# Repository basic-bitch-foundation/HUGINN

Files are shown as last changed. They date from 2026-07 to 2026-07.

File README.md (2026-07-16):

# HUGINN
 Introduction
--------------------------------------------
Huginn was crow of Odin (Greek God), He was messenger of hims. Thus this will be your personal messenger, let u communicate w/ hommies in any 9 realms.

It is a LoRa ( Long Range ) powered  pocket off grid pager.

## Build

It have BOM, Custom PCB, 3D printed Enclosure, buttons and suport.
Download All files(.stp) from Enclosure printable folder and print 'em
 > It uses M2 screw everywhere
 > For part link please download .odf not .csv
 > In assembly u may see the MCU as colliding with PCB dw! it just cz I can't remove the header pins. :lollll:

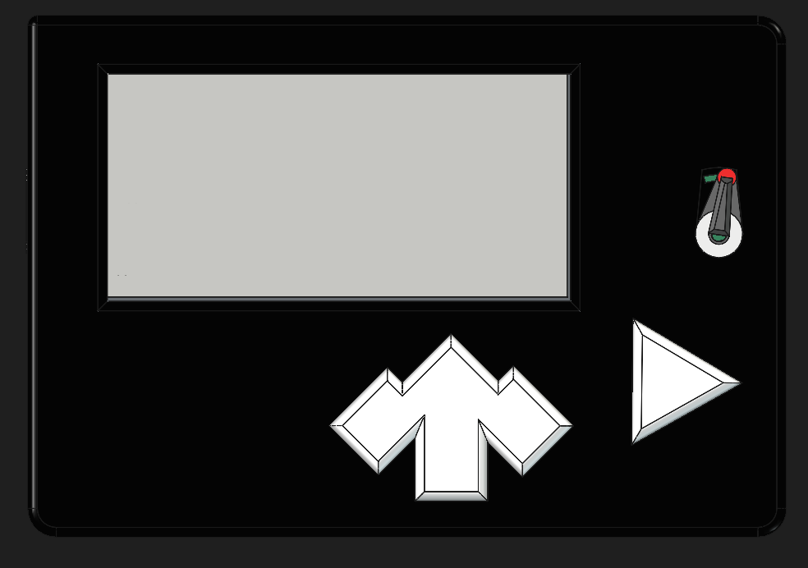
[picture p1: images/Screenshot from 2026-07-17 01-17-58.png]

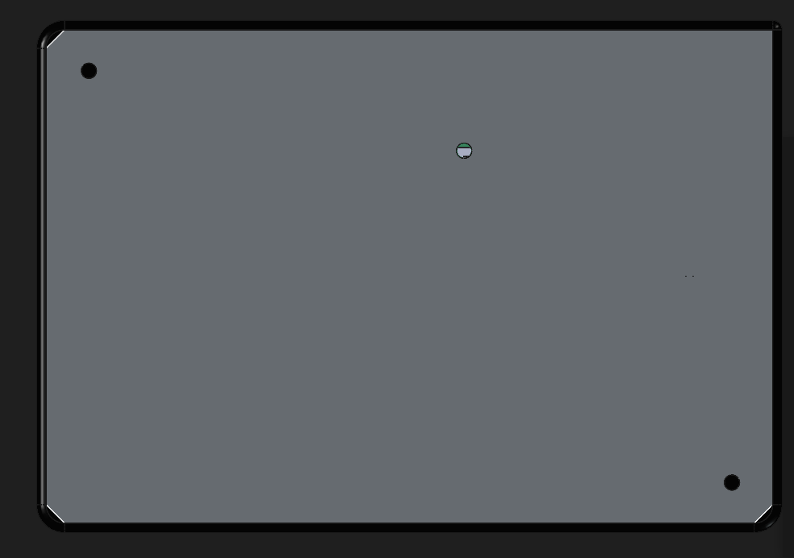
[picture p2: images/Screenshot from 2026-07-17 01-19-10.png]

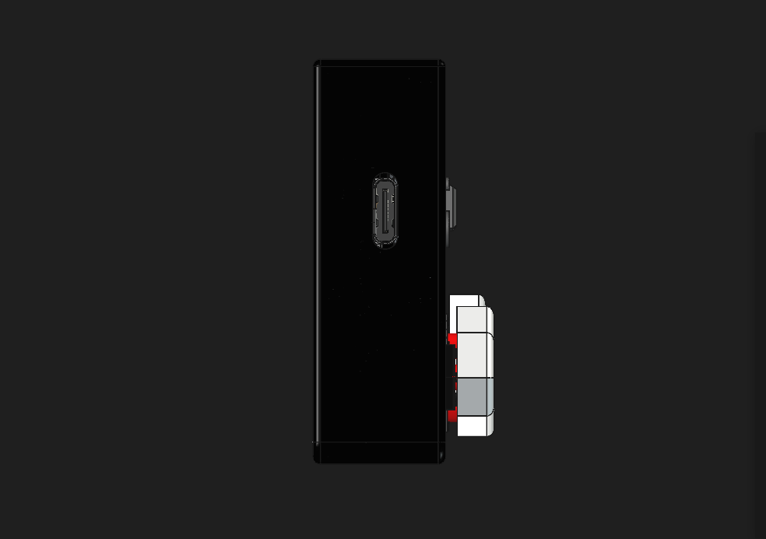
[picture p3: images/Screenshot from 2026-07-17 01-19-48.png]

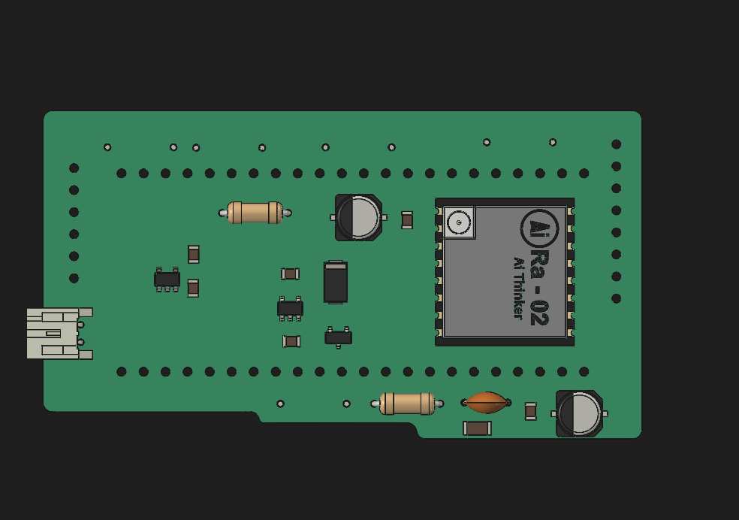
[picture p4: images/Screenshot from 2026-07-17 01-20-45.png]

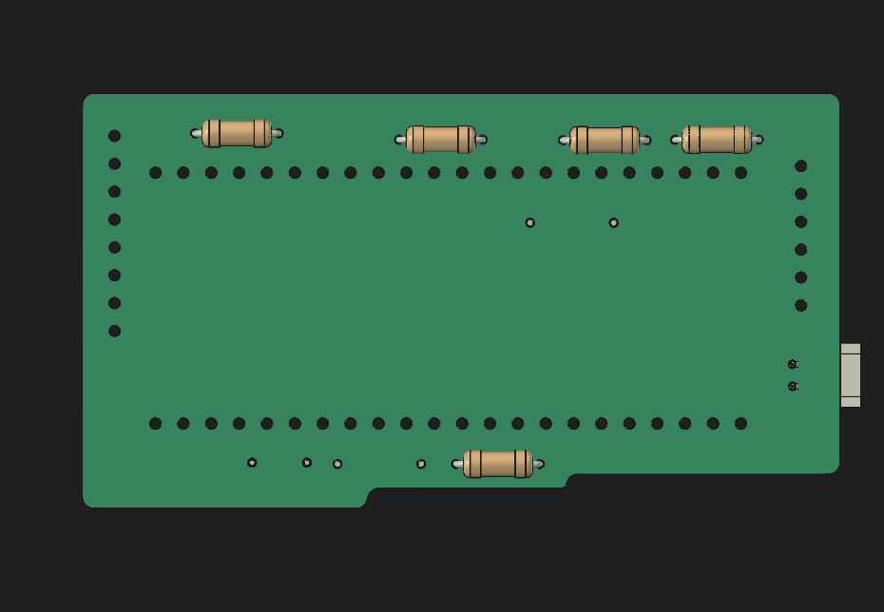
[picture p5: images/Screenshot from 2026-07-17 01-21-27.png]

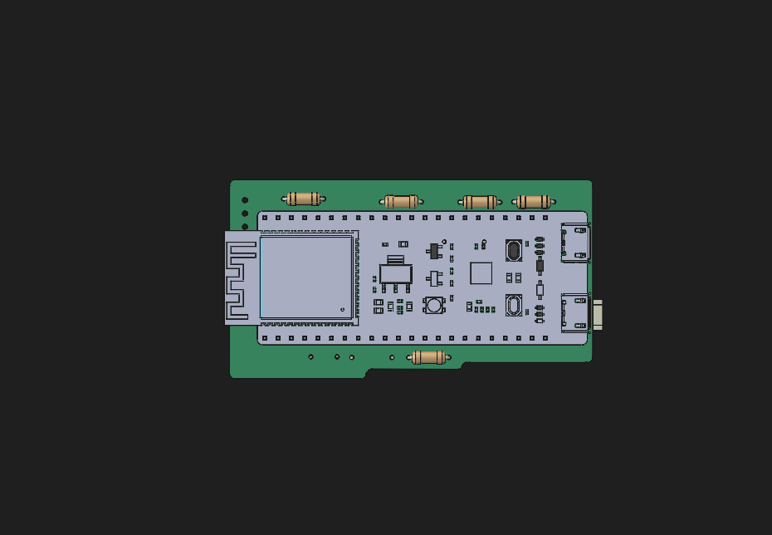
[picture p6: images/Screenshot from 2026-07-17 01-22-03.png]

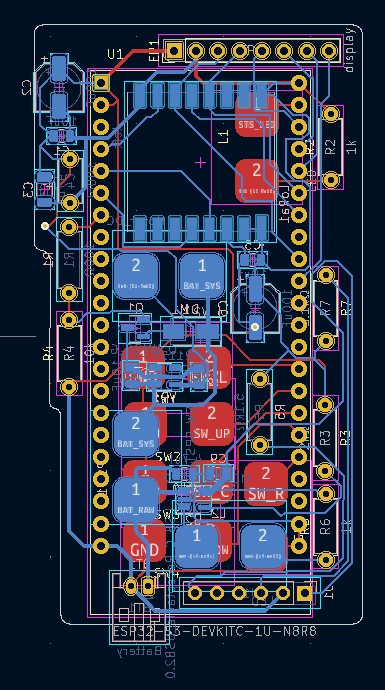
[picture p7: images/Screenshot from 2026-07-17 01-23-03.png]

 ### Instructions
 First comes the MCU U hve to castellated solder it on top of the board or can use very low height header pins

 then Display as display I gave in BOM, Have 8 pin(Goes to HAT) to 8 , I will suggest to solder 'em direct , though half height n 2.54 header can use.
 
 Stating with solder all component On PCB ,
 As most part will be connected using wire to component to SMD solder Pad.
 1. Part u need to connect like this: ( Component--> wire--> Smd pad)
 > 5 switches
 >2 LEDs
 >Battery (optional)

 2. The semi rotating switch have two part one is switch with rod dropped and a pad
 put the switch inside carv and then fix the pad on left face of rod so i can press momentary switch.
 Then, Screw it from bellow (Enough clamp so that It can't move freely but can move!)

 3. As most part have support in Enclosure but gluing it make it smooth
 4. Glue the disc motor that will send vibration through body
 5. I don't gave the outing for LED cz It was ruining the Aesthetics of E ink's calm there so Any who want to see the charging status can place it nea usb input or a small hole behind panel

## Code
This is basic firmware code u can compile and flash it in MCU using Platform.io (a extension in VS code) or using Thonny (IDE)

## How to use it:
As pager need to be quick I added three code fn!
and a local converter:
So U navigate up/down 
between
143 ( I Love u!)
505 ( SOS )
etc.
the click the send button when reciver will reciver get it wil automaticall converted in their own device
. This save the bytes of daya is trasmitting and saving time 

# AI- decl.
I use like very little < 10% AI for code. 

# Outro
Made for Hackclub <3 by Saksham (A.K.A bbb)
Feel free to contribute :heart:

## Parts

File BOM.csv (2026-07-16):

Reference | Qty | Category | Component | Value | Manufacturer | Part Number / Model | Package / Footprint | Description | Supplier Link | Price (USD) | Price (INR) | Notes
U1 | 1 | Microcontrollers | ESP32-S3 Dev Board | N8R8 | Espressif | ESP32-S3-DEVKITC-1-N8R8 | DEVKITC-1U (castellated module) | ESP32-S3 Development Board (8MB Flash / 8MB PSRAM) | here |  | 1304.1 | Used as system module - not a bare SoC
LoRa1 | 1 | RF Modules | LoRa Transceiver Module | 433MHz | Ai-Thinker | RA-02 (SX1278) | SMD Module - 16 pin (2x8 top/bottom) | 433 MHz LoRa Transceiver Module (SX1278-based) | here |  | 301 | Confirm 433 MHz vs 868/915 MHz variant needed for your region
VR1 | 1 | Power Management | LDO Voltage Regulator | 3.3V | Diodes Inc. | AP2112K-3.3 | SOT-23-5 | 3.3V 600mA Low Dropout Voltage Regulator | here |  | 26
U2 | 1 | Power Management | LiPo Charge Controller IC | - | Microchip | MCP73831T-2ACI/OT | SOT-23-5 | Single-Cell Li-Po/Li-Ion Linear Charge Management IC | here |  | 71.83
J1 | 1 | Connectors | USB Type-C Receptacle | - |  |  | SMD Type-C 16-pin | USB Type-C Power/Data Connector (USB 2.0) | here |  | 34 | different from footprint
BT1 | 1 | Connectors | Battery Connector | 2-pin | JST | PH-2 (S2B-PH-K) | JST-PH 2.00mm 2-pin Horizontal | JST-PH 2-Pin Battery Connector | here |  | 8 | Can skip very optional
EP1 | 1 | Connectors | E-Ink Display Connector | 8-pin | Generic | PinHeader-1x08-2.54mm | 2.54mm Pitch 1x08 Vertical Header | 2.13" SPI E-Ink Display Header (8-pin) | here |  | 1478
PSW1 | 1 | Switches | Momentary switch | Power | Generic |  | SMD 2-pin |  | here |  | 39
SW1 | 1 | Switches | Tactile Push Button | Left | Generic | Tactile SMD 2-pin | SolderPad 5x5mm SMD | Tactile Push Button (Left / Navigation) | here |  | 1.05
SW2 | 1 | Switches | Tactile Push Button | Up | Generic | Tactile SMD 2-pin | SolderPad 5x5mm SMD | Tactile Push Button (Up / Navigation) | "
SW3 | 1 | Switches | Tactile Push Button | Send | Generic | Tactile SMD 2-pin | SolderPad 5x5mm SMD | Tactile Push Button (Center / Select) | "
SW4 | 1 | Switches | Tactile Push Button | Down | Generic | Tactile SMD 2-pin | SolderPad 5x5mm SMD | Tactile Push Button (Down / Navigation) | "
SW5 | 1 | Switches | Tactile Push Button | Right | Generic | Tactile SMD 2-pin | SolderPad 5x5mm SMD | Momentary Tactile Push Button (Right / Navigation) | here
L1 | 1 | LEDs | Status LED | diode led | Generic | LED-0805 | SolderPad 5x5mm SMD | Status Indicator LED
L2 | 1 | LEDs | Charge Status LED | " | Generic | LED-0805 | SolderPad 5x5mm SMD | Battery Charge Status LED
Q1 | 1 | Transistors | N-Channel MOSFET | - | Generic | BSS138 | SOT-23 | N-Channel MOSFET (Motor Driver Switch) | here |  | 2.02
D1 | 1 | Diodes | Flyback/Protection Diode | - | Generic | 1N4148 or equiv. | SMA | Diode (Motor Flyback Protection)
R1 | 1 | Resistors | Resistor | 100? | Generic | RC-Series | Axial THT (DIN0207) | 100? Resistor (LoRa Reset Gate)
R2 | 1 | Resistors | Resistor | 1k? | Generic | RC-Series | Axial THT (DIN0207) | 1k? Resistor (Status LED Current Limit) |  |  |  | regional prices and availiblity varries
R3 | 1 | Resistors | Resistor | 2k? | Generic | RC-Series | Axial THT (DIN0207) | 2k? Resistor (Charge IC PROG - Sets Charge Current) |  |  |  | regional prices and availiblity varries
R4 | 1 | Resistors | Resistor | 10k? | Generic | RC-Series | Axial THT (DIN0207) | 10k? Resistor (MOSFET Gate Pulldown) |  |  |  | regional prices and availiblity varries
R5 | 1 | Resistors | Resistor | 5.1k? | Generic | RC-Series | Axial THT (DIN0207) | 5.1k? Resistor (USB-C CC1 Pull-down) |  |  |  | regional prices and availiblity varries
R6 | 1 | Resistors | Resistor | 1k? | Generic | RC-Series | Axial THT (DIN0207) | 1k? Resistor (Charge LED Current Limit)
R7 | 1 | Resistors | Resistor | 5.1k? | Generic | RC-Series | Axial THT (DIN0207) | 5.1k? Resistor (USB-C CC2 Pull-down)
C1 | 1 | Capacitors | Capacitor | 10uF | Generic | C-Series | 0805 SMD | 10uF Ceramic Capacitor (E-Ink Supply Decoupling)
C2 | 1 | Capacitors | Capacitor | 100uF | Generic | CP-Elec | 5x5.3mm Electrolytic | 100uF Electrolytic Capacitor (E-Ink Bulk Decoupling)
C3 | 1 | Capacitors | Capacitor | 47uF | Generic | C-Series | 1206 SMD | 47uF Capacitor (ESP32 Supply Decoupling)
C4 | 1 | Capacitors | Capacitor | 100nF | Generic | C-Disc | THT Disc 5mm | 100nF Capacitor (ESP32 Supply Decoupling)
C5 | 1 | Capacitors | Capacitor | 10uF | Generic | C-Series | 0805 SMD | 10uF Capacitor (LoRa Module Supply Decoupling)
C6 | 1 | Capacitors | Capacitor | 100uF | Generic | CP-Elec | 5x5.3mm Electrolytic | 100uF Electrolytic Capacitor (LoRa Module Bulk Decoupling)
C7 | 1 | Capacitors | Capacitor | 10uF | Generic | C-Series | 0805 SMD | 10uF Capacitor (LDO Input Decoupling)
C8 | 1 | Capacitors | Capacitor | 10uF | Generic | C-Series | 0805 SMD | 10uF Capacitor (LDO Output Decoupling)
C9 | 1 | Capacitors | Capacitor | 4.7uF | Generic | C-Series | 0805 SMD | 4.7uF Capacitor (Charge IC VDD Decoupling)
C10 | 1 | Capacitors | Capacitor | 4.7uF | Generic | C-Series | 0805 SMD | 4.7uF Capacitor (Charge IC VBAT Decoupling) |  |  |  | "
M1 | 1 | Motors | Coin Vibration Motor | - | Generic | Coin Vibe 10mm | SolderPad 5x5mm SMD | Coin Vibration Motor (Haptic Feedback) | here |  | 73
 |  |  |  |  |  |  |  |  |  | TOTAL = | ~3500

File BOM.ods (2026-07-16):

Reference | Qty | Category | Component | Value | Manufacturer | Part Number / Model | Package / Footprint | Description | Supplier Link | Price (USD) | Price (INR) | Notes
U1 | 1 | Microcontrollers | ESP32-S3 Dev Board | N8R8 | Espressif | ESP32-S3-DEVKITC-1-N8R8 | DEVKITC-1U (castellated module) | ESP32-S3 Development Board (8MB Flash / 8MB PSRAM) | here (https://www.google.com/aclk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) |  | 1304.1 | Used as system module - not a bare SoC
LoRa1 | 1 | RF Modules | LoRa Transceiver Module | 433MHz | Ai-Thinker | RA-02 (SX1278) | SMD Module - 16 pin (2x8 top/bottom) | 433 MHz LoRa Transceiver Module (SX1278-based) | here (https://www.google.com/aclk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) |  | 301 | Confirm 433 MHz vs 868/915 MHz variant needed for your region
VR1 | 1 | Power Management | LDO Voltage Regulator | 3.3V | Diodes Inc. | AP2112K-3.3 | SOT-23-5 | 3.3V 600mA Low Dropout Voltage Regulator | here (https://robu.in/product/ap2112k-3-3trg1-diodes-inc-ldo-fixed-3-3v-0-6a-40-to-85deg-c/) |  | 26
U2 | 1 | Power Management | LiPo Charge Controller IC | - | Microchip | MCP73831T-2ACI/OT | SOT-23-5 | Single-Cell Li-Po/Li-Ion Linear Charge Management IC | here (https://www.digikey.in/en/products/detail/microchip-technology/MCP73831T-2ACI-OT/964301) |  | 71.83
J1 | 1 | Connectors | USB Type-C Receptacle | - |  |  | SMD Type-C 16-pin | USB Type-C Power/Data Connector (USB 2.0) | here (https://www.google.com/aclk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) |  | 34 | different from footprint
BT1 | 1 | Connectors | Battery Connector | 2-pin | JST | PH-2 (S2B-PH-K) | JST-PH 2.00mm 2-pin Horizontal | JST-PH 2-Pin Battery Connector | here (https://robu.in/product/2-pin-jst-xh-2-54mm-pitch-plug-and-socket-with-cable-10-pcs/) |  | 8 | Can skip very optional
EP1 | 1 | Connectors | E-Ink Display Connector | 8-pin | Generic | PinHeader-1x08-2.54mm | 2.54mm Pitch 1x08 Vertical Header | 2.13" SPI E-Ink Display Header (8-pin) | here (https://www.evelta.com/2-13inch-e-paper-e-ink-display-module-for-raspberry-pi-pico/?sku=061-19406) |  | 1478
PSW1 | 1 | Switches | Momentary switch | Power | Generic |  | SMD 2-pin |  | here (https://electronicspices.com/product/12x12x9mm-black-color-tactile-momentary-push-button-switch-pack-of-10) |  | 39
SW1 | 1 | Switches | Tactile Push Button | Left | Generic | Tactile SMD 2-pin | SolderPad 5x5mm SMD | Tactile Push Button (Left / Navigation) | here (https://www.google.com/aclk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) |  | 1.05
SW2 | 1 | Switches | Tactile Push Button | Up | Generic | Tactile SMD 2-pin | SolderPad 5x5mm SMD | Tactile Push Button (Up / Navigation) | "
SW3 | 1 | Switches | Tactile Push Button | Send | Generic | Tactile SMD 2-pin | SolderPad 5x5mm SMD | Tactile Push Button (Center / Select) | "
SW4 | 1 | Switches | Tactile Push Button | Down | Generic | Tactile SMD 2-pin | SolderPad 5x5mm SMD | Tactile Push Button (Down / Navigation) | "
SW5 | 1 | Switches | Tactile Push Button | Right | Generic | Tactile SMD 2-pin | SolderPad 5x5mm SMD | Momentary Tactile Push Button (Right / Navigation) | here (https://electronicspices.com/product/12x12x9mm-black-color-tactile-momentary-push-button-switch-pack-of-10)
L1 | 1 | LEDs | Status LED | diode led | Generic | LED-0805 | SolderPad 5x5mm SMD | Status Indicator LED
L2 | 1 | LEDs | Charge Status LED | " | Generic | LED-0805 | SolderPad 5x5mm SMD | Battery Charge Status LED
Q1 | 1 | Transistors | N-Channel MOSFET | - | Generic | BSS138 | SOT-23 | N-Channel MOSFET (Motor Driver Switch) | here (https://robu.in/product/bss138-slkor-50v-220ma-3-5ω10v220ma-225mw-1-6v1ma-1-n-channel-sot-23-mosfets-rohs/) |  | 2.02
D1 | 1 | Diodes | Flyback/Protection Diode | - | Generic | 1N4148 or equiv. | SMA | Diode (Motor Flyback Protection)
R1 | 1 | Resistors | Resistor | 100Ω | Generic | RC-Series | Axial THT (DIN0207) | 100Ω Resistor (LoRa Reset Gate)
R2 | 1 | Resistors | Resistor | 1kΩ | Generic | RC-Series | Axial THT (DIN0207) | 1kΩ Resistor (Status LED Current Limit) |  |  |  | regional prices and availiblity varries
R3 | 1 | Resistors | Resistor | 2kΩ | Generic | RC-Series | Axial THT (DIN0207) | 2kΩ Resistor (Charge IC PROG - Sets Charge Current) |  |  |  | regional prices and availiblity varries
R4 | 1 | Resistors | Resistor | 10kΩ | Generic | RC-Series | Axial THT (DIN0207) | 10kΩ Resistor (MOSFET Gate Pulldown) |  |  |  | regional prices and availiblity varries
R5 | 1 | Resistors | Resistor | 5.1kΩ | Generic | RC-Series | Axial THT (DIN0207) | 5.1kΩ Resistor (USB-C CC1 Pull-down) |  |  |  | regional prices and availiblity varries
R6 | 1 | Resistors | Resistor | 1kΩ | Generic | RC-Series | Axial THT (DIN0207) | 1kΩ Resistor (Charge LED Current Limit)
R7 | 1 | Resistors | Resistor | 5.1kΩ | Generic | RC-Series | Axial THT (DIN0207) | 5.1kΩ Resistor (USB-C CC2 Pull-down)
C1 | 1 | Capacitors | Capacitor | 10uF | Generic | C-Series | 0805 SMD | 10uF Ceramic Capacitor (E-Ink Supply Decoupling)
C2 | 1 | Capacitors | Capacitor | 100uF | Generic | CP-Elec | 5x5.3mm Electrolytic | 100uF Electrolytic Capacitor (E-Ink Bulk Decoupling)
C3 | 1 | Capacitors | Capacitor | 47uF | Generic | C-Series | 1206 SMD | 47uF Capacitor (ESP32 Supply Decoupling)
C4 | 1 | Capacitors | Capacitor | 100nF | Generic | C-Disc | THT Disc 5mm | 100nF Capacitor (ESP32 Supply Decoupling)
C5 | 1 | Capacitors | Capacitor | 10uF | Generic | C-Series | 0805 SMD | 10uF Capacitor (LoRa Module Supply Decoupling)
C6 | 1 | Capacitors | Capacitor | 100uF | Generic | CP-Elec | 5x5.3mm Electrolytic | 100uF Electrolytic Capacitor (LoRa Module Bulk Decoupling)
C7 | 1 | Capacitors | Capacitor | 10uF | Generic | C-Series | 0805 SMD | 10uF Capacitor (LDO Input Decoupling)
C8 | 1 | Capacitors | Capacitor | 10uF | Generic | C-Series | 0805 SMD | 10uF Capacitor (LDO Output Decoupling)
C9 | 1 | Capacitors | Capacitor | 4.7uF | Generic | C-Series | 0805 SMD | 4.7uF Capacitor (Charge IC VDD Decoupling)
C10 | 1 | Capacitors | Capacitor | 4.7uF | Generic | C-Series | 0805 SMD | 4.7uF Capacitor (Charge IC VBAT Decoupling) |  |  |  | "
M1 | 1 | Motors | Coin Vibration Motor | - | Generic | Coin Vibe 10mm | SolderPad 5x5mm SMD | Coin Vibration Motor (Haptic Feedback) | here (https://robu.in/product/erm-coin-vibration-motor-8-mm-dia-2-mm-width/) |  | 73
 |  |  |  |  |  |  |  |  |  | TOTAL = | ~3500

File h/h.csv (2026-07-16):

Source: | /home/bbb/HUGINN/HUGINN/h/h.kicad_sch
Date: | Thu Jul 16 22:22:25 2026
Tool: | Eeschema 6.0.11-2627ca5db0~126~ubuntu22.04.1
Generator: | /usr/share/kicad/plugins/bom_csv_grouped_by_value_with_fp.py
Component Count: | 35
Ref | Qnty | Value | Cmp name | Footprint | Description | Vendor
BT1, | 1 | Battery | Conn_01x02 | Connector_JST:JST_PH_S2B-PH-K_1x02_P2.00mm_Horizontal | Generic connector, single row, 01x02, script generated (kicad-library-utils/schlib/autogen/connector/)
C1, C7, C8, | 3 | 10uF | C | Capacitor_SMD:C_0805_2012Metric | Unpolarized capacitor
C2, C6, | 2 | 100uF | C | Capacitor_SMD:CP_Elec_5x5.3 | Unpolarized capacitor
C3, | 1 | 47uF | C | Capacitor_SMD:C_1206_3216Metric | Unpolarized capacitor
C4, | 1 | 100nf | C | Capacitor_THT:C_Disc_D5.0mm_W2.5mm_P5.00mm | Unpolarized capacitor
C5, | 1 | 10uf | C | Capacitor_SMD:C_0805_2012Metric | Unpolarized capacitor
C9, C10, | 2 | 4.7uF | C | Capacitor_SMD:C_0805_2012Metric | Unpolarized capacitor
D1, | 1 | D | D | Diode_SMD:D_SMA | Diode
EP1, | 1 | display | Conn_01x08 | Connector_PinHeader_2.54mm:PinHeader_1x08_P2.54mm_Vertical | Generic connector, single row, 01x08, script generated (kicad-library-utils/schlib/autogen/connector/)
J1, | 1 | USB_C_Receptacle_USB2.0 | USB_C_Receptacle_USB2.0 | Connector_PinSocket_2.54mm:PinSocket_1x06_P2.54mm_Vertical | USB 2.0-only Type-C Receptacle connector
L1, L2, | 2 | LED | LED | solderwirepad_1_02_SMD:SolderWirePad_1x02_SMD_5x5mm | Light emitting diode
LoRa1, | 1 | left | Conn_02x08_Top_Bottom | RA-02_LORA:MODULE_RA-02_LORA | Generic connector, double row, 02x08, top/bottom pin numbering scheme (row 1: 1...pins_per_row, row2: pins_per_row+1 ... num_pins), script generated (kicad-library-utils/schlib/autogen/connector/)
M1, | 1 | Motor_DC | Motor_DC | solderwirepad_1_02_SMD:SolderWirePad_1x02_SMD_5x5mm | DC Motor
PSW1, | 1 | SW_SPST | SW_SPST | solderwirepad_1_02_SMD:SolderWirePad_1x02_SMD_5x5mm | Single Pole Single Throw (SPST) switch
Q1, | 1 | Q_NMOS_GDS | Q_NMOS_GDS | Package_TO_SOT_SMD:SOT-23 | N-MOSFET transistor, gate/drain/source
R1, | 1 | 100Ω | R | Resistor_THT:R_Axial_DIN0207_L6.3mm_D2.5mm_P7.62mm_Horizontal | Resistor
R2, R6, | 2 | 1k | R | Resistor_THT:R_Axial_DIN0207_L6.3mm_D2.5mm_P7.62mm_Horizontal | Resistor
R3, | 1 | 2kΩ | R | Resistor_THT:R_Axial_DIN0207_L6.3mm_D2.5mm_P7.62mm_Horizontal | Resistor
R4, | 1 | 10k | R | Resistor_THT:R_Axial_DIN0207_L6.3mm_D2.5mm_P7.62mm_Horizontal | Resistor
R5, R7, | 2 | 5.1kΩ | R | Resistor_THT:R_Axial_DIN0207_L6.3mm_D2.5mm_P7.62mm_Horizontal | Resistor
SW1, | 1 | SW_L | SW_SPST | solderwirepad_1_02_SMD:SolderWirePad_1x02_SMD_5x5mm | Single Pole Single Throw (SPST) switch
SW2, | 1 | SW_UP | SW_SPST | solderwirepad_1_02_SMD:SolderWirePad_1x02_SMD_5x5mm | Single Pole Single Throw (SPST) switch
SW3, | 1 | SW_C | SW_SPST | solderwirepad_1_02_SMD:SolderWirePad_1x02_SMD_5x5mm | Single Pole Single Throw (SPST) switch
SW4, | 1 | SW_DW | SW_SPST | solderwirepad_1_02_SMD:SolderWirePad_1x02_SMD_5x5mm | Single Pole Single Throw (SPST) switch
SW5, | 1 | SW_R | SW_SPST | solderwirepad_1_02_SMD:SolderWirePad_1x02_SMD_5x5mm | Single Pole Single Throw (SPST) switch
U1, | 1 | ESP32-S3-DEVKITC-1U-N8R8 | ESP32-S3-DEVKITC-1U-N8R8 | ESP32-n8r8:ESP32-S3-DEVKITC-1-N8R8
U2, | 1 | MCP73831-2-OT | MCP73831-2-OT | Package_TO_SOT_SMD:SOT-23-5 | Single cell, Li-Ion/Li-Po charge management controller, 4.20V, Tri-State Status Output, in SOT23-5 package
VR1, | 1 | AP2112K-3.3 | AP2112K-3.3 | Package_TO_SOT_SMD:SOT-23-5 | 600mA low dropout linear regulator, with enable pin, 3.8V-6V input voltage range, 3.3V fixed positive output, SOT-23-5

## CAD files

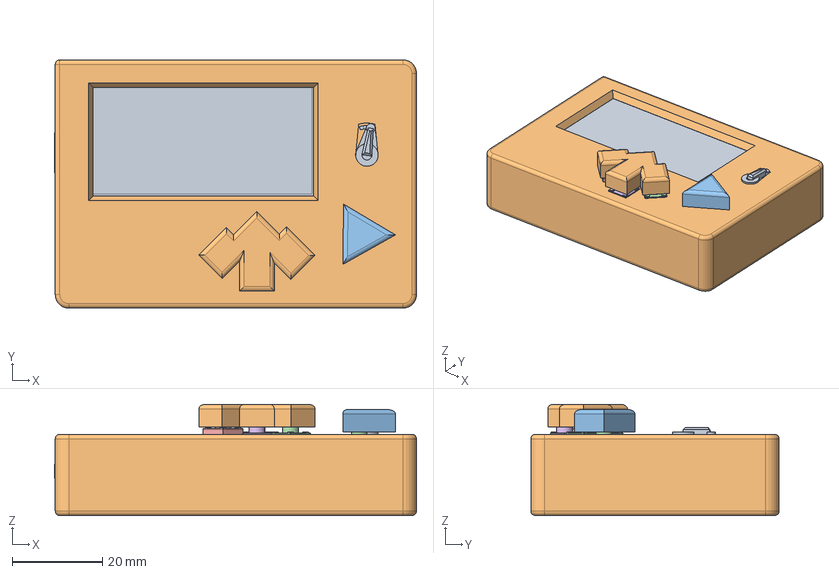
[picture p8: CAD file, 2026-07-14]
Assembly/Assembly.FCStd
80.2 x 55.0 x 24.6 mm
2.13inch e-Paper HAT bwr v3
buttonRot
buttonRot001
buttonRot002
buttonRot003
buttonRot004
Silk
Silk001
Silk002
resistor3 (13)
Silk003
Silk004
Silk005
Pads
Silk006
Silk007
Pads001
Silk008
Silk009
Silk010
Silk011
Silk012
Silk013
Silk014
Silk015
Silk016
Silk017
Silk018
Silk019
Pads002
Silk020
Silk021
Pads003
Silk022
Silk023
resistor3 (12)
Silk024
Silk025
Pads004
Silk026
Silk027
Silk028
Silk029
Silk030
Silk031
Silk032
Frame:1
PcbPins:1
ConPins:1
Mold:1
Silk033
Silk034
Silk035
Silk036
Silk037
Silk038
Pads005
Silk039
Silk040
Silk041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

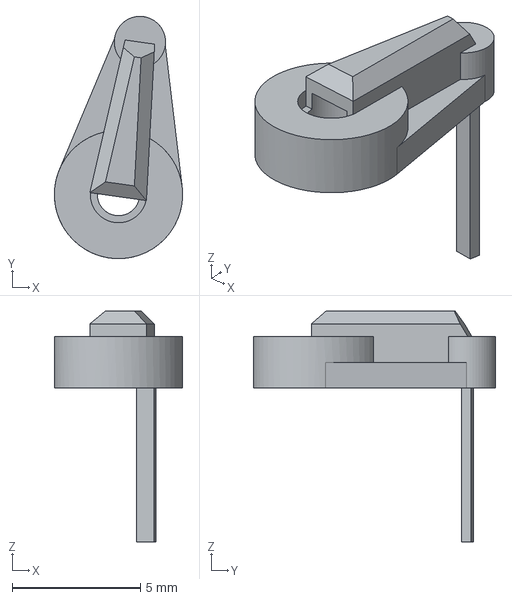
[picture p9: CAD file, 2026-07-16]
Enclosure_printables/Power_button.step
5.00 x 9.44 x 9.00 mm

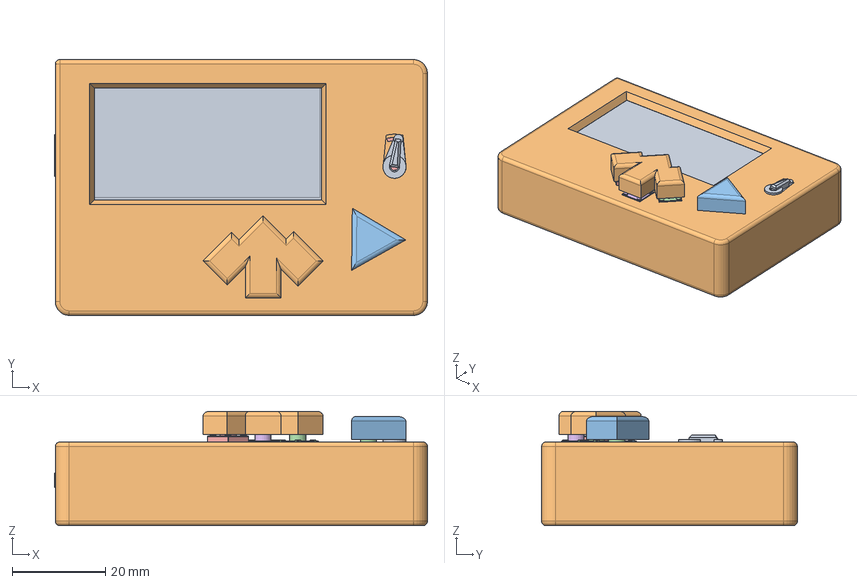
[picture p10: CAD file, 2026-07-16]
h/frame.FCStd
80.2 x 55.0 x 24.6 mm
2.13inch e-Paper HAT bwr v3
buttonRot
buttonRot001
buttonRot002
buttonRot003
buttonRot004
Pcb_edae
R7_R_Axial_DIN0207_L63mm_D25mm_P762mm_Horizontal_d80642af86ee x 7
C8_C_0805_2012Metric_f9a5720865e0 x 6
VR1_SOT_23_5_eb58e82a12df x 2
BT1_JST_S2B_PH_K_344eb8960ea7
LoRa_Module_RA-02 v1
LoRa_Module_RA-02 v001
LoRa_Module_RA-02 v002
LoRa_Module_RA-02 v003
LoRa_Module_RA-02 v004
LoRa_Module_RA-02 v005
LoRa_Module_RA-02 v006
LoRa_Module_RA-02 v007
LoRa_Module_RA-02 v008
D1_D_SMA_107b6f5b705b
C4_C_Disc_D50mm_W25mm_P500mm_8d80121a20e2
C6_CP_Elec_5x53_d21821c00178 x 2
Q1_SOT_23_dbff6dcb7132
C3_C_1206_3216Metric_78cae1aa1cba
Silk
Silk001
Silk002
resistor3 (13)
Silk003
Silk004
Silk005
Pads
Silk006
Silk007
Pads001
Silk008
Silk009
Silk010
Silk011
Silk012
Silk013
Silk014
Silk015
Silk016
Silk017
Silk018
Silk019
Pads002
Silk020
Silk021
Pads003
Silk022
Silk023
resistor3 (12)
Silk024
Silk025
Pads004
Silk026
Silk027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

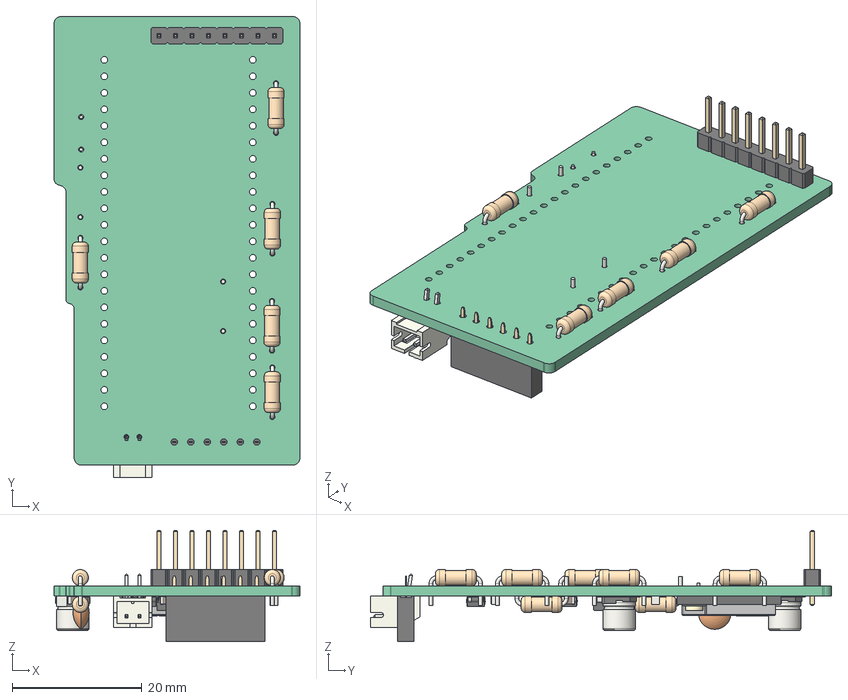
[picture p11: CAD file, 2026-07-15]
PCB/frame-h.step
37.9 x 71.0 x 17.1 mm
Local_CS_edae
Pcb_edae
PCB_Sketch_edae
EP1_PinHeader_1x08_P254mm_Vertical_c5de0936e516
R7_R_Axial_DIN0207_L63mm_D25mm_P762mm_Horizontal_d80642af86ee x 7
C8_C_0805_2012Metric_f9a5720865e0 x 6
VR1_SOT_23_5_eb58e82a12df x 2
BT1_JST_S2B_PH_K_344eb8960ea7
LoRa_Module_RA-02 v1
LoRa_Module_RA-02 v001
LoRa_Module_RA-02 v002
LoRa_Module_RA-02 v003
LoRa_Module_RA-02 v004
LoRa_Module_RA-02 v005
LoRa_Module_RA-02 v006
LoRa_Module_RA-02 v007
LoRa_Module_RA-02 v008
D1_D_SMA_107b6f5b705b
J1_PinSocket_1x06_P254mm_Vertical_59cfc1da216a
C4_C_Disc_D50mm_W25mm_P500mm_8d80121a20e2
C6_CP_Elec_5x53_d21821c00178 x 2
Q1_SOT_23_dbff6dcb7132
C3_C_1206_3216Metric_78cae1aa1cba

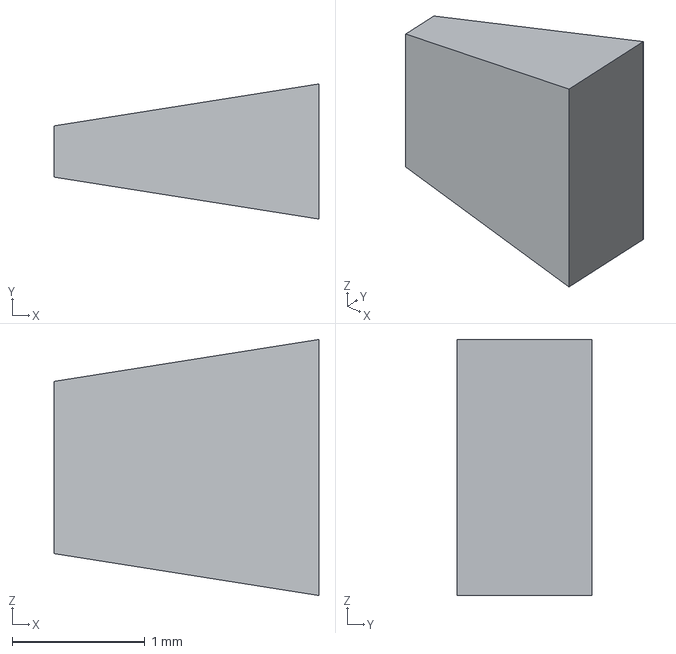
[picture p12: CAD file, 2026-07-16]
Enclosure_printables/momentary_pad.step
2.00 x 1.02 x 1.93 mm

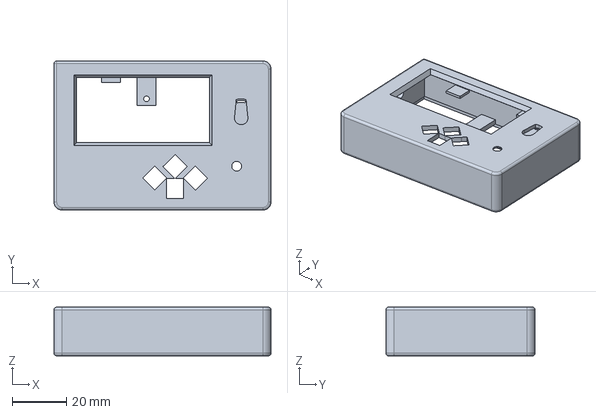
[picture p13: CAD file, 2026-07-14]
h/frame-Body.step
80.0 x 55.0 x 18.0 mm

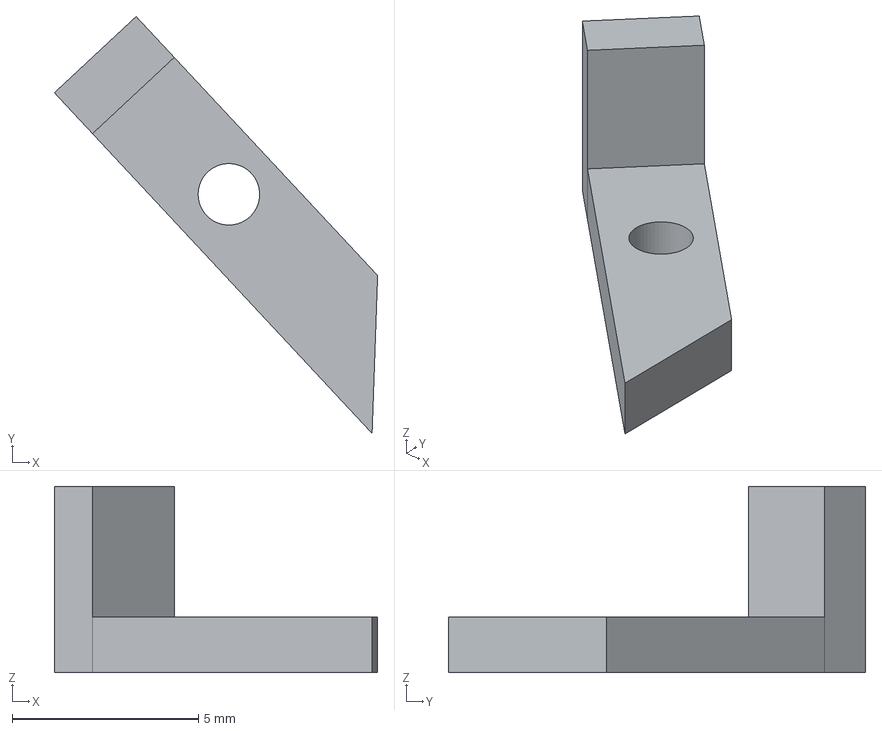
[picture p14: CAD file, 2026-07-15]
Enclosure_printables/Button_support.step
8.67 x 11.2 x 5.00 mm

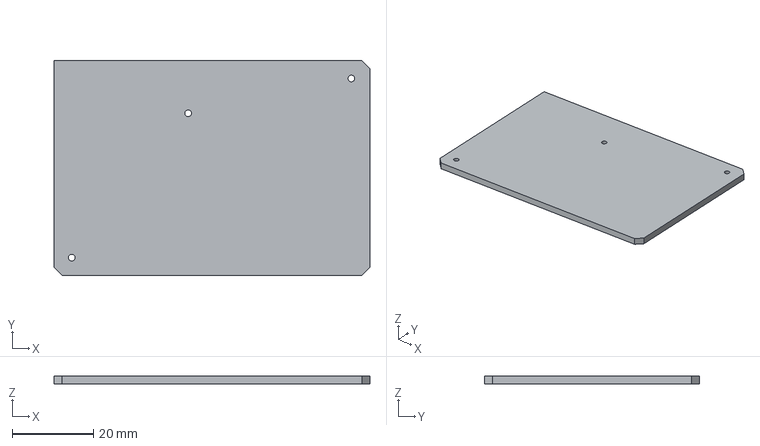
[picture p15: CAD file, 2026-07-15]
Enclosure_printables/Back_panel.step
78.0 x 53.0 x 2.00 mm

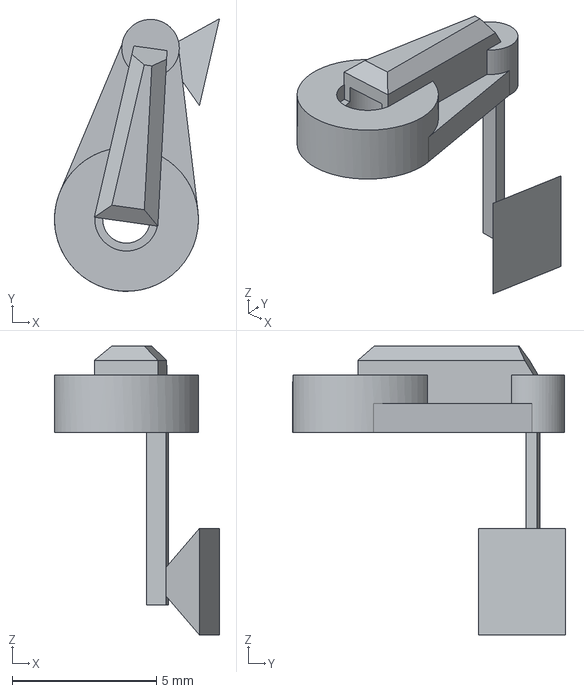
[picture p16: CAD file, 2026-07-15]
Enclosure_printables/Power_switch.step
5.73 x 9.47 x 10.0 mm

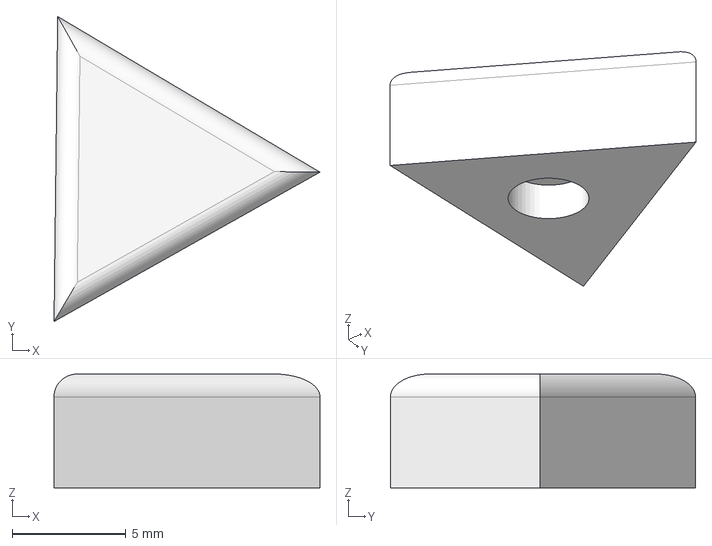
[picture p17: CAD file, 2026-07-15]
Enclosure_printables/Send_btn.step
11.7 x 13.4 x 5.00 mm

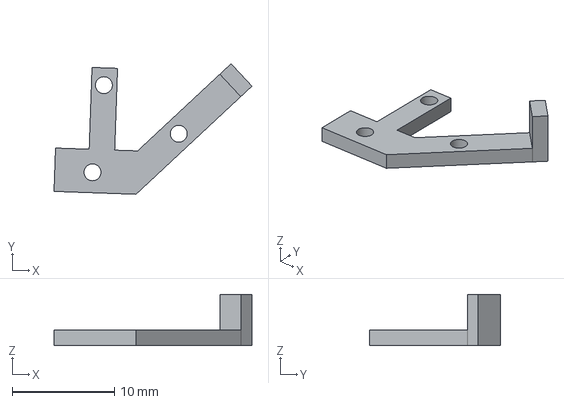
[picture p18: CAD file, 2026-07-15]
Enclosure_printables/Button_support_2.step
19.4 x 12.8 x 5.00 mm

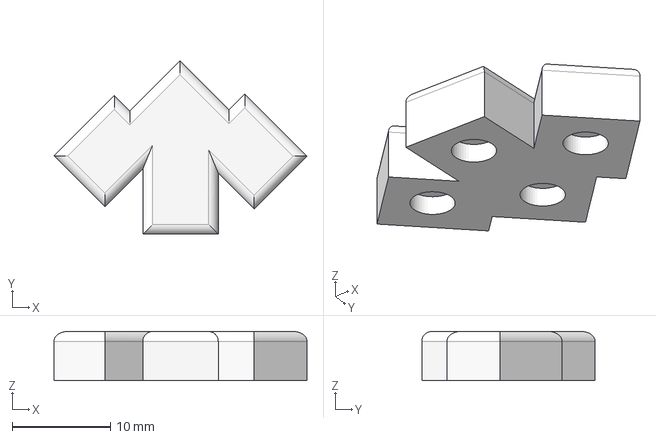
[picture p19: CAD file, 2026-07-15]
Enclosure_printables/Navigation_btn.step
25.8 x 17.7 x 5.00 mm

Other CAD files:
h/h.FCStd
Enclosure_printables/frame-Body.step
Enclosure_printables/Back_panel.stl
Enclosure_printables/Button_support.stl
Enclosure_printables/Button_support_2.stl
Enclosure_printables/Navigation_btn.stl
Enclosure_printables/Power_button.stl
Enclosure_printables/Send_btn.stl
Enclosure_printables/frame-Body.stl
Enclosure_printables/momentary_pad.stl
h/frame-Body.stl

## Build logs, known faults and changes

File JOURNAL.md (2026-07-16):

Title: Huginn
Aurthor: Saksham 
Description: It is a LoRa (Long-Range) off grid Pager, people can communticate in remote areas. Named upon messenger crow of Odin.
**Total Time Elapsed: 43 Hours 34 mins** without code 

>Note: SO Basically I didn't have exact duration for every sesssion, I have dates frame , duration and Lapse for it.
# June 7 - June 26 (7 sessions & 3 Lapses)
**Time Elapsed for this time frame: 9 hrs 27mins + 14hrs 30 mins + 2 hrs 57 mins = 26 hrs 54 mins**
**[Lapse Link_1](https://lapse.hackclub.com/timelapse/QDs2V-pR2Pm_)**
**[Lapse Link_2](https://lapse.hackclub.com/timelapse/tjxTxSEeeEpX)**
**[Lapse Link_3](https://lapse.hackclub.com/timelapse/QCqySz1Eb1_g)**

**I can't recall exact time/date per sessions**
#session_1
Started with BOM.

Not exact with costing, but the parts I will need.
Made a notepad file for that.

So initially BOM includes:

* Seeed Studio XIAO ESP32-S3
* LoRa SX1278 Ra-02 Ai-Thinker

Then antenna for LoRa. I first thought of a direct-connect U.FL antenna, but it wasn't available.

So I thought of adding an SMA to U.FL pigtail cable and then an SMA antenna. It also gives a good look, like a pager with an antenna. Matches with my design.

Although It can work without antenna too!

Then eInk display.

So I thought of using a raw 2.7-inch eInk panel and then designing the FFC connector to it.

But as I'm a pro noobie in hardware, I planned to use a module with SPI interface embedded with 8 outputs.
Cz FFC have like 23 pin thinnest

So I fixed on the Waveshare 2.7-inch eInk display module with SPI interface.

Battery most prob 3.7V LiPo.
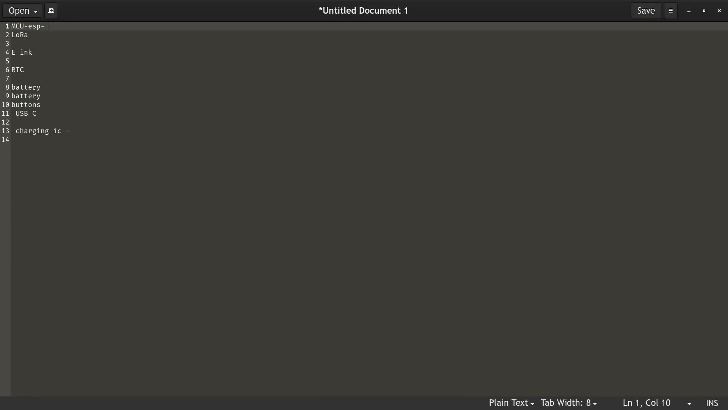
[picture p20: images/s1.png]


#Session_2
So at very first I went for Seeed Studio XIAO ESP32-S3 and started designing the schematic in KiCad with Conn_01x07 pins twice as per ESP32-S3 pinout, then Conn_01x08 twice for the LoRa module.

Then a single Conn_01x08 for the eInk display.

Then labeled all things and pinouts, updated the same in the notepad, then added capacitors, etc.

------------------------------ THEN HIT A PROBLEM ------------------------------

I, a dumaah, didn't account for the GPIO pins required.

And the Seeed Studio ESP32-S3 ran out of GPIOs.

So I searched for another MCU and landed at:

ESP32-S3 DevKitC-1 N8R8

Which has a whopping 45 GPIOs, but the size is big.

Then calculated the size dimensions of the pager body, etc.

It fits. :yayayay:

So for the symbol in KiCad I used Conn_02x22_Counter_Clockwise for ESP32-S3 DevKitC-1 N8R8, but it didn't work well due to many naming issues.

And I'm new to KiCad as well.

So searched for its symbol and found it in the KiCad library, but it was with different pinout and naming.

I got it, but the pins were a little disordered.

#session_3

So I edited the symbol and changed the pin names and order as per my requirement, and then added it to my project library.

[LAPSE FREEZED HERE A LITTLE]

After that I learned two things.

Dropped using local labels because of visibility and also for better understanding of the schematic, and used Global Labels.

Then wired MCU, Display, and LoRa.

Added battery and a main switch.

Then researched about the charging part and landed on MCP73831, which is a single-cell LiPo charger IC.

Added USB_C_RECEPTACLE for charging and also added Conn_01x02 for battery connection.

But here I will obviously not use all pins of USB-C. Most likely I will use the same type because I use VBUS and SHIELD with MCP73831.

Then for voltage regulator I thought of using MT3608 but switched to MCP1640, but couldn't find either one.

#Session_4

I researched a lot of regulators for 3.3V like MCP1700T, SSP9193, TPS63020.

All of them were either out of stock or not available to ship to India.

At last I found a niche sussy website selling AP2112K-3.3V.

Then using two power labels: BAT_SYS and BAT_RAW.

Fixed connections, added capacitors and resistors for charging, eInk display between battery labels, etc.

Connected regulator, charging IC, battery labels, USB-C pins, and LEDs for charging indication.

Then comes the navigation part.

For UI/UX navigation I planned for 4 buttons, but I think 5 are needed.

So added one more button for menu and used 5 buttons for:

* Up
* Down
* Left
* Right
* Menu

Connected them with MCU as required.

Now the vibration motor part.

I used an N-type MOSFET for vibration motor controlling.

I really wanted good haptics.
okay so i can upload all images so i give the drive link check out all images

#Session_5
So I started with fixing some capacitance Issue in schemtaics 
then for good structure and understanding I rearrange the schematics each working parts in seprate boxes and label them.

>  Footprint time 

As I'm new to Hardware and PCBs I didn't know that there are two types of component SMD and THT
So I change the many footprint of resistor and capacitor to THT cz SMD ones are very tiny and I wasn't sure that I could solder them or not. :confused-smash:

Then Comes Lora problem now Intially Lora is in two pats of Conn symbol.
but obv I have to assing footprint to any one
so I have to download symbol and footprint of Lora 
There fore I have to re-wire the Lora in schematics.

Then I researched (little and not continously) for other symbol's footprints. And started assinging.

Now for many things I dont want it soldered to PCB board  such as switches, Leds so I can move these parts by soldering wire on pcb on soldering pads
. Problem was there wasn't any soldering Pads of correct size neither two pads together.
So I searched for it, can't find any.
I started makin' one in footprint editor.
And used it accordingly.

Then some little search for correct usb pin so i go for a break board that can be used.
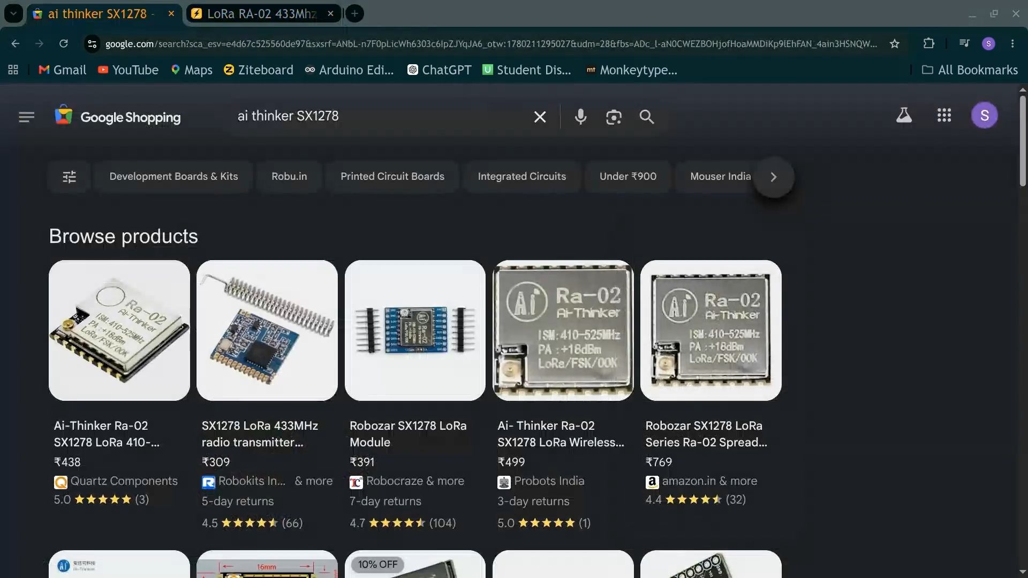
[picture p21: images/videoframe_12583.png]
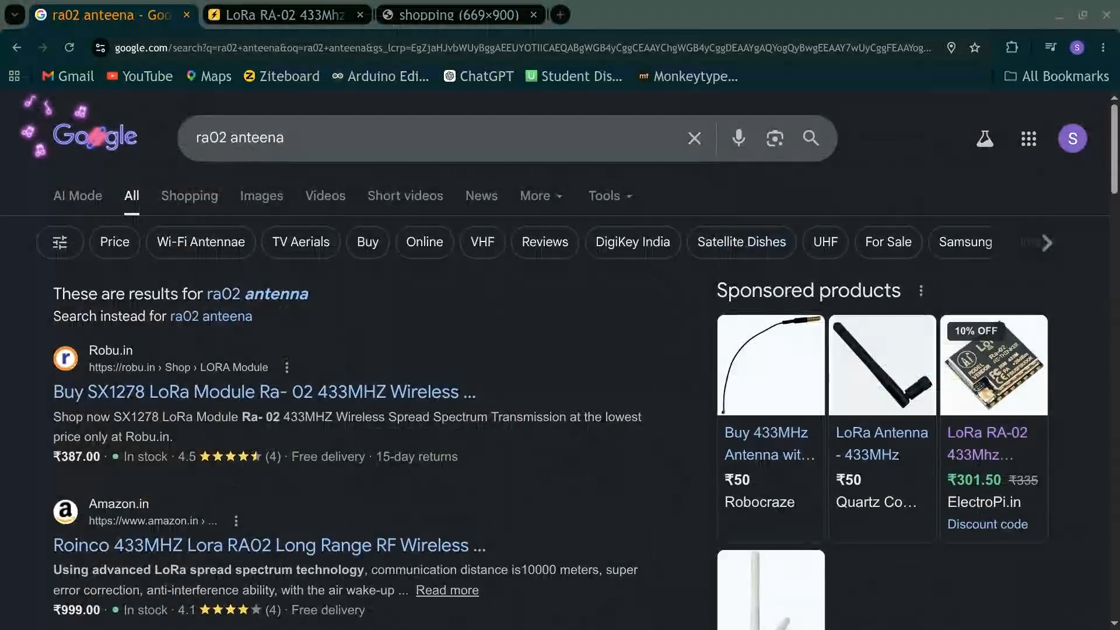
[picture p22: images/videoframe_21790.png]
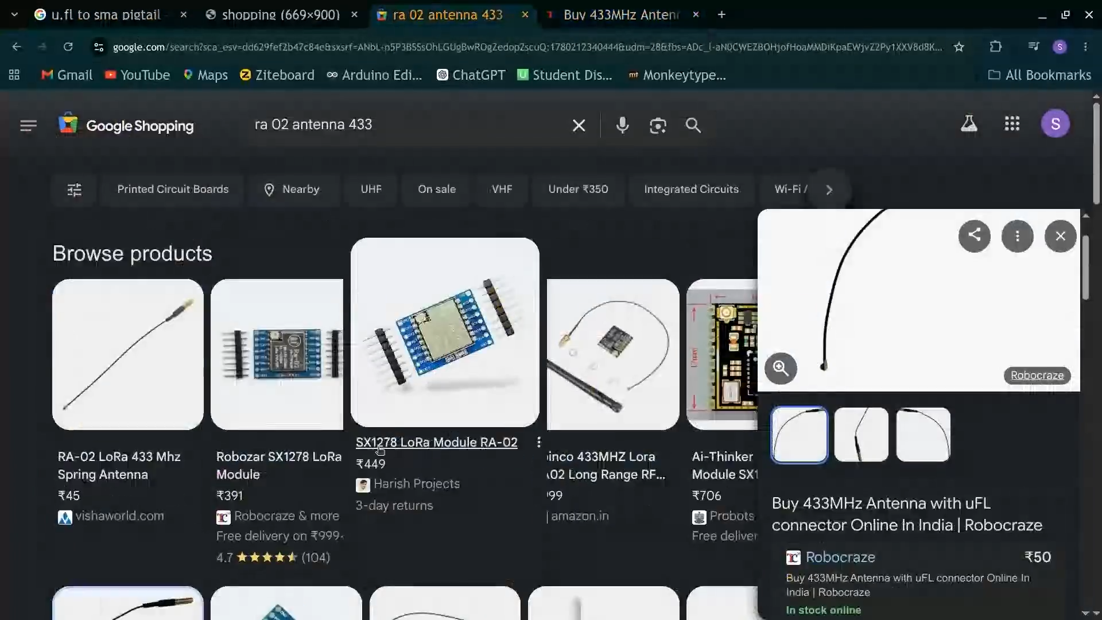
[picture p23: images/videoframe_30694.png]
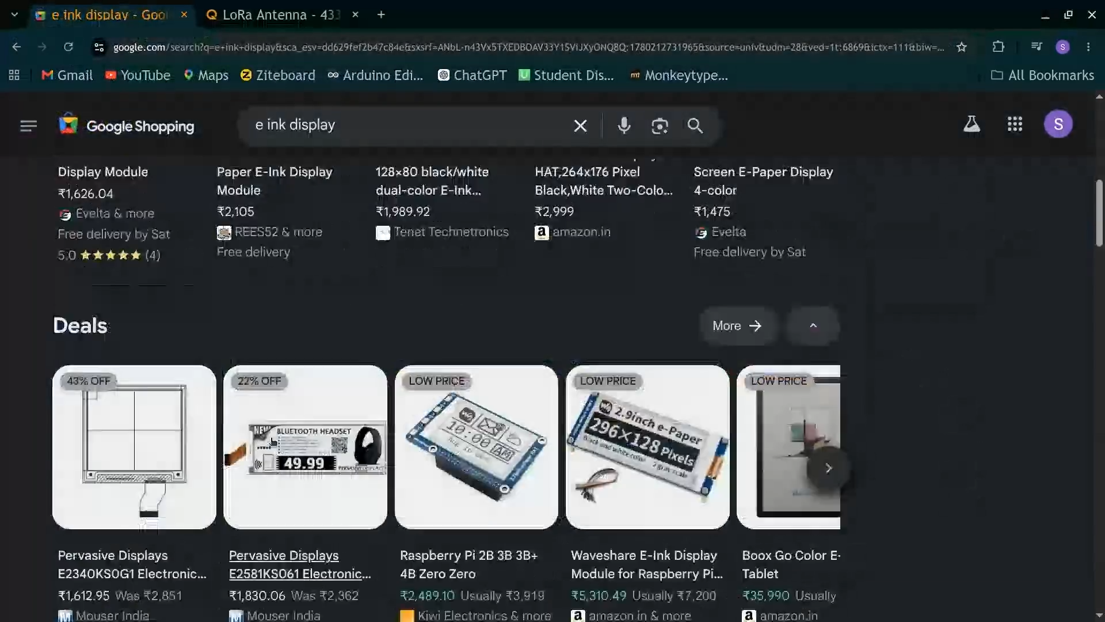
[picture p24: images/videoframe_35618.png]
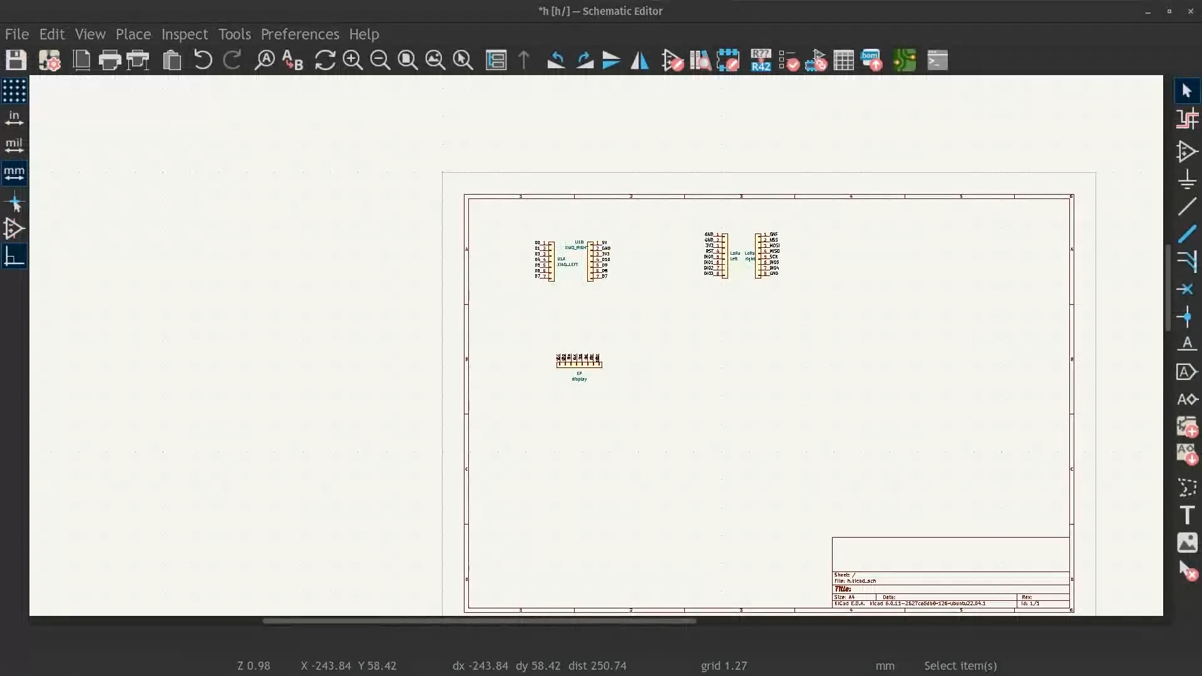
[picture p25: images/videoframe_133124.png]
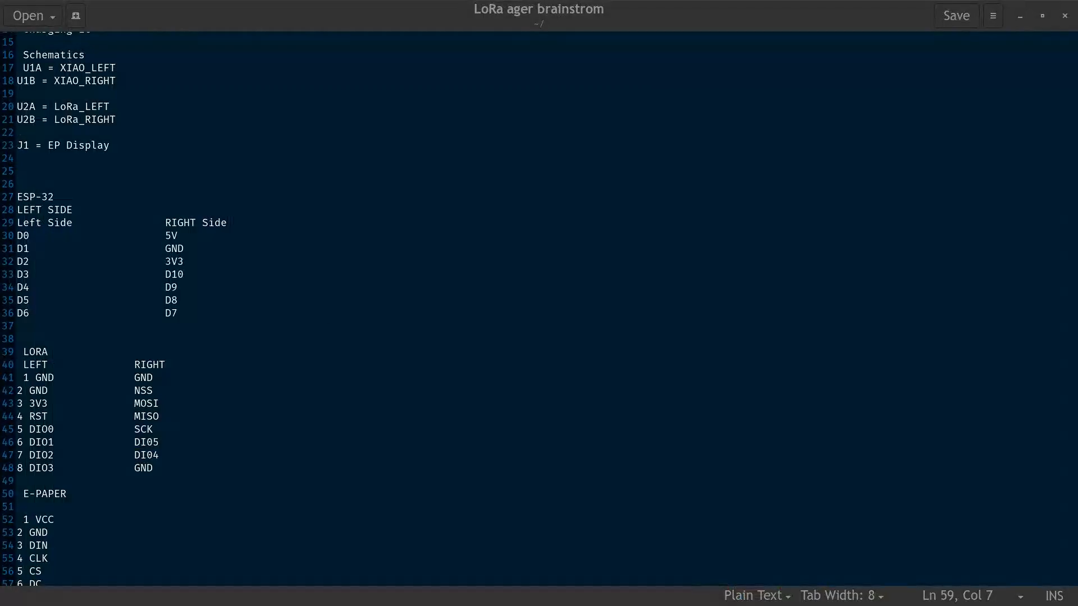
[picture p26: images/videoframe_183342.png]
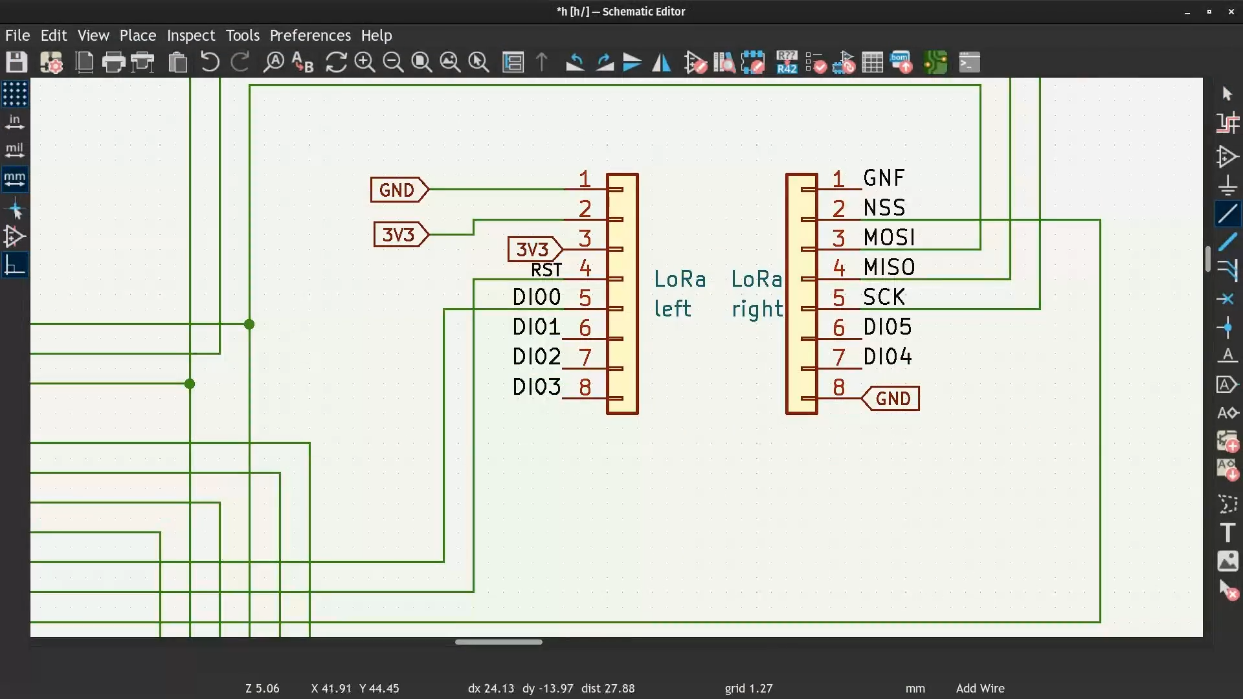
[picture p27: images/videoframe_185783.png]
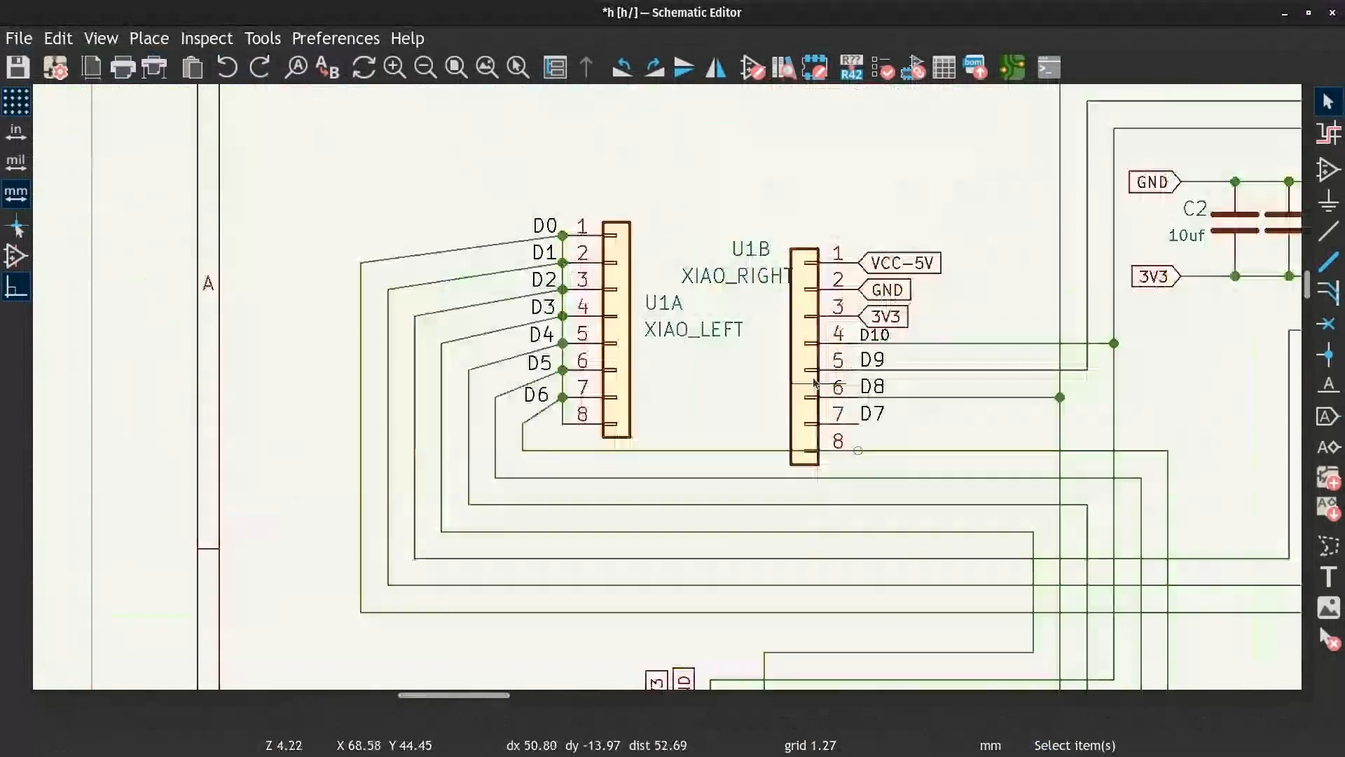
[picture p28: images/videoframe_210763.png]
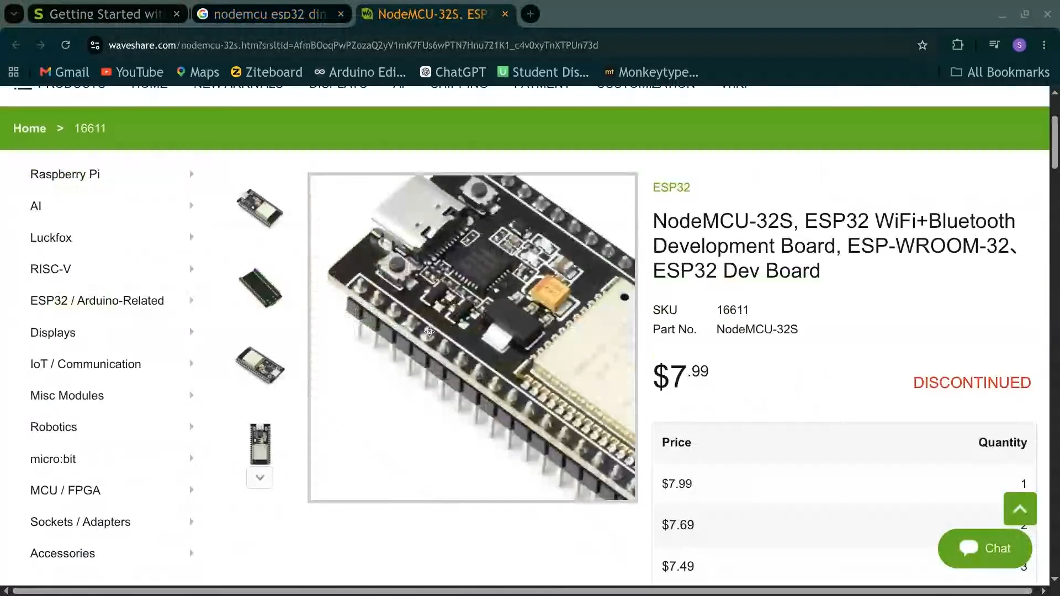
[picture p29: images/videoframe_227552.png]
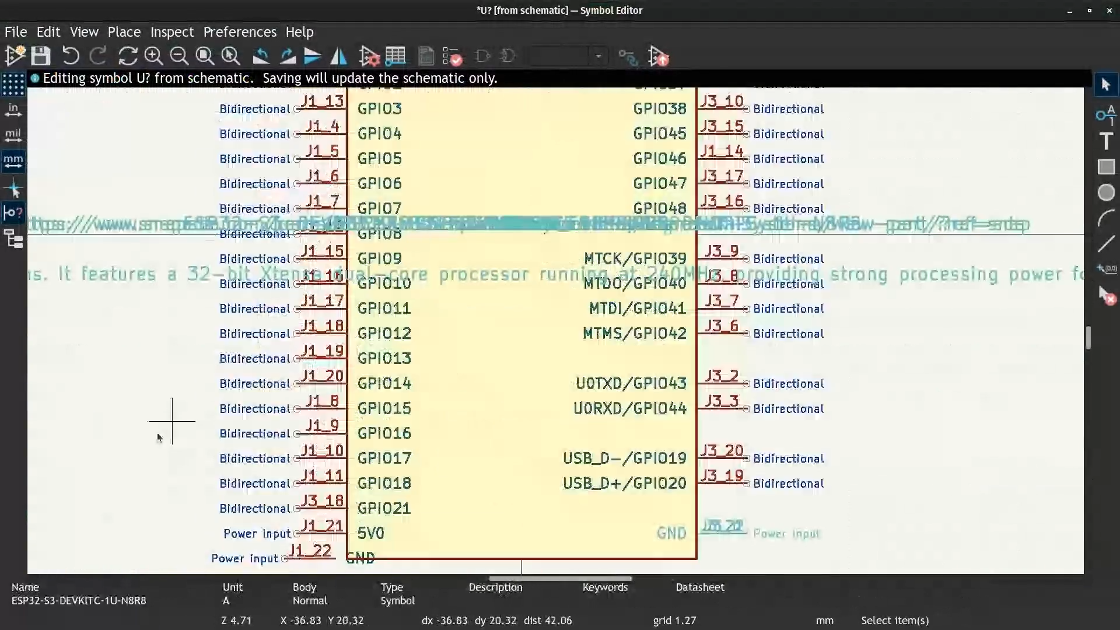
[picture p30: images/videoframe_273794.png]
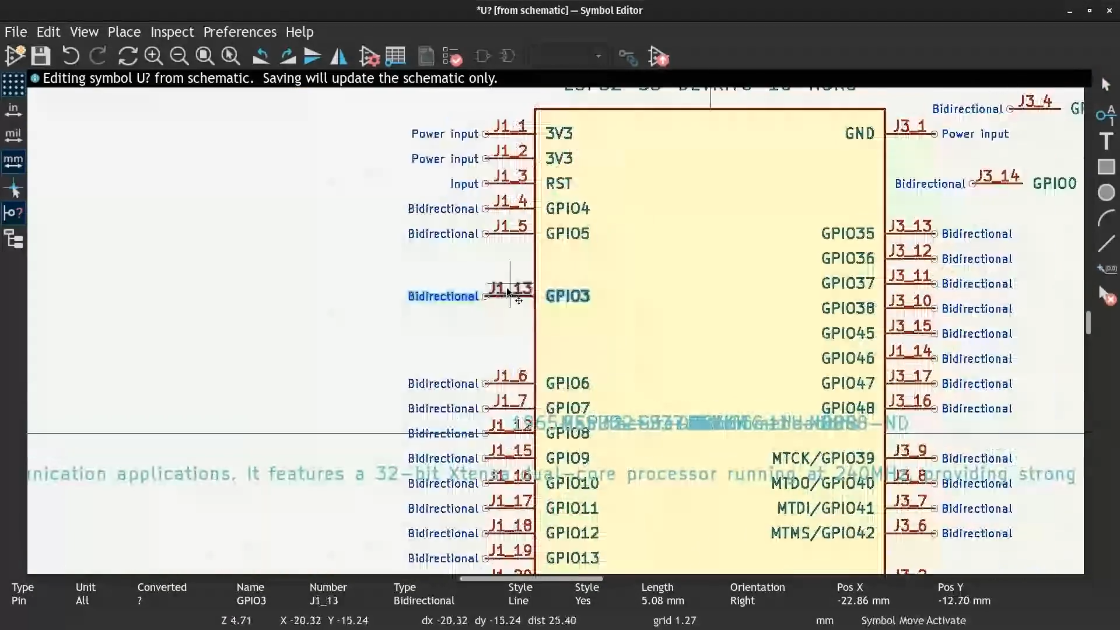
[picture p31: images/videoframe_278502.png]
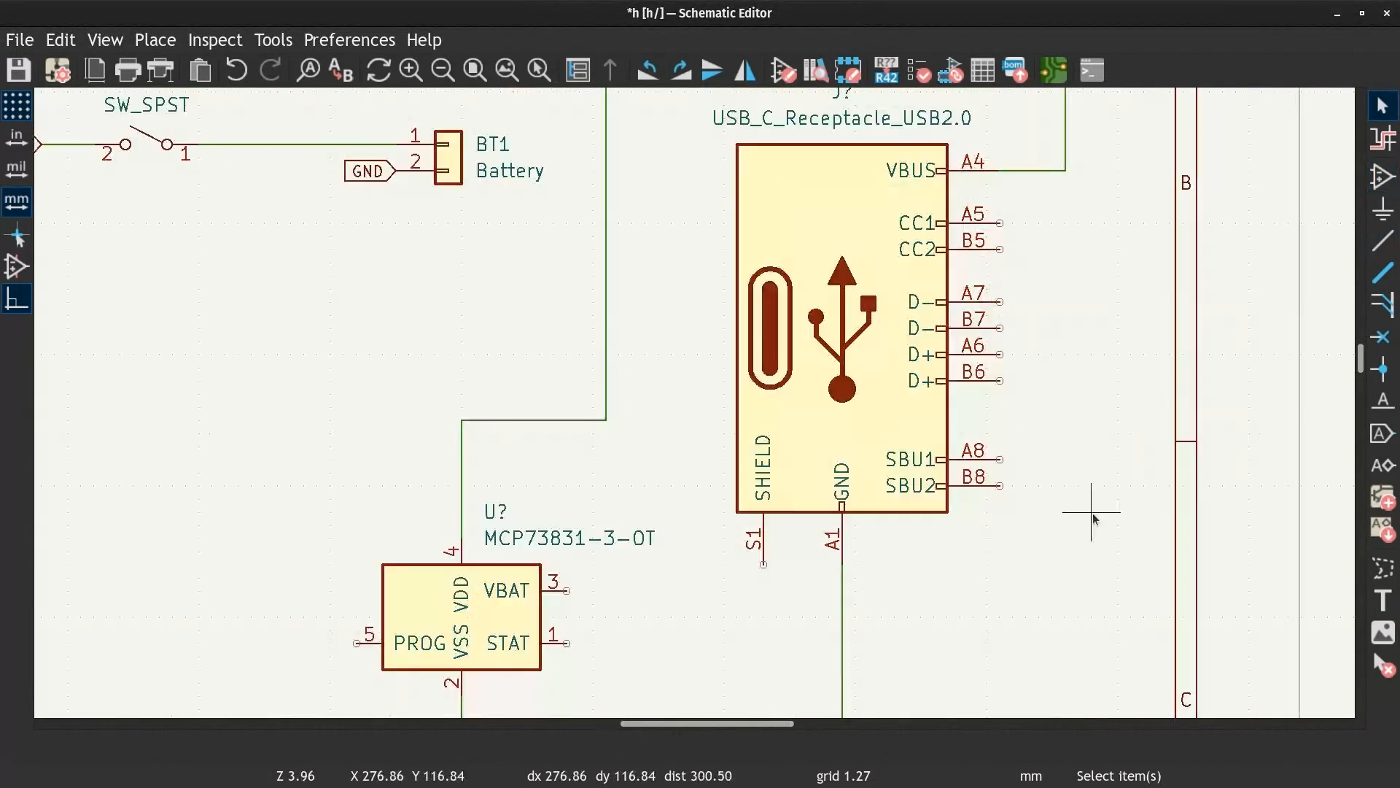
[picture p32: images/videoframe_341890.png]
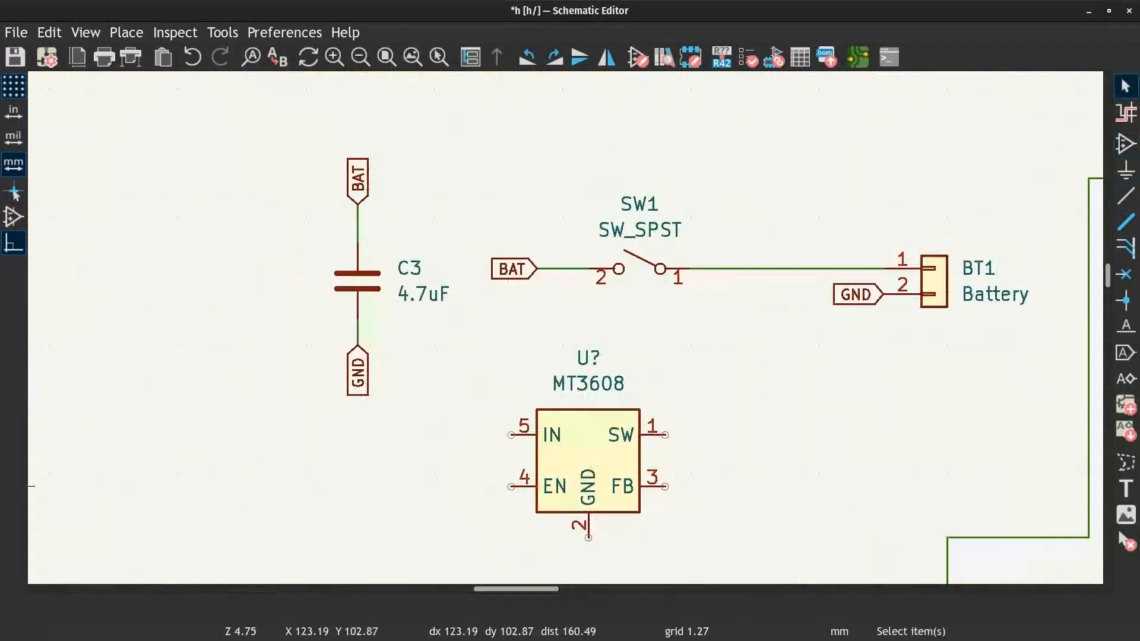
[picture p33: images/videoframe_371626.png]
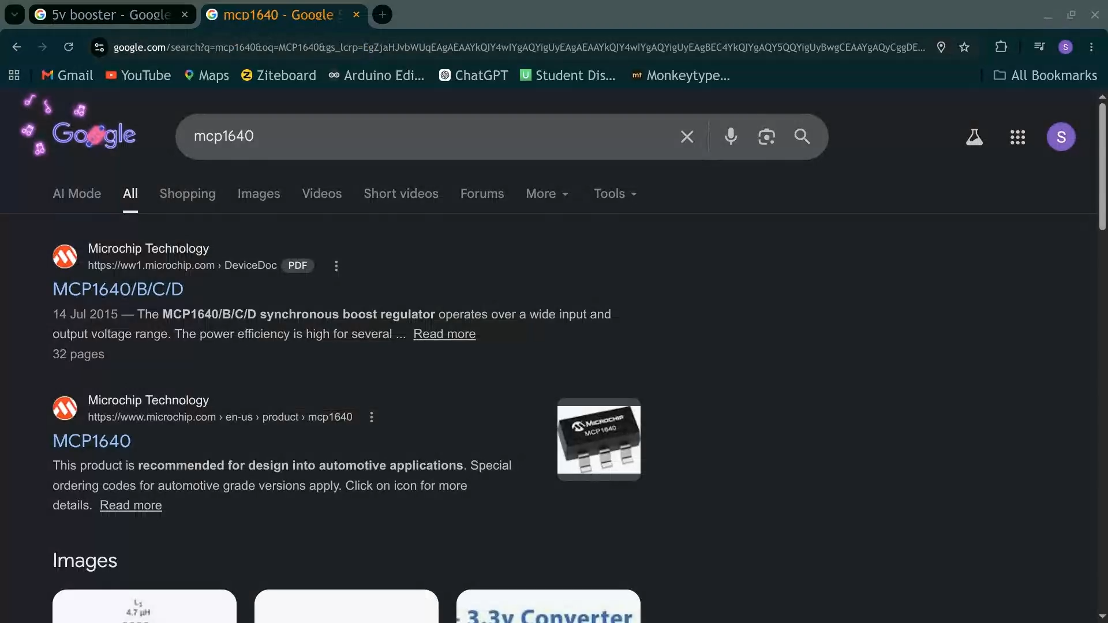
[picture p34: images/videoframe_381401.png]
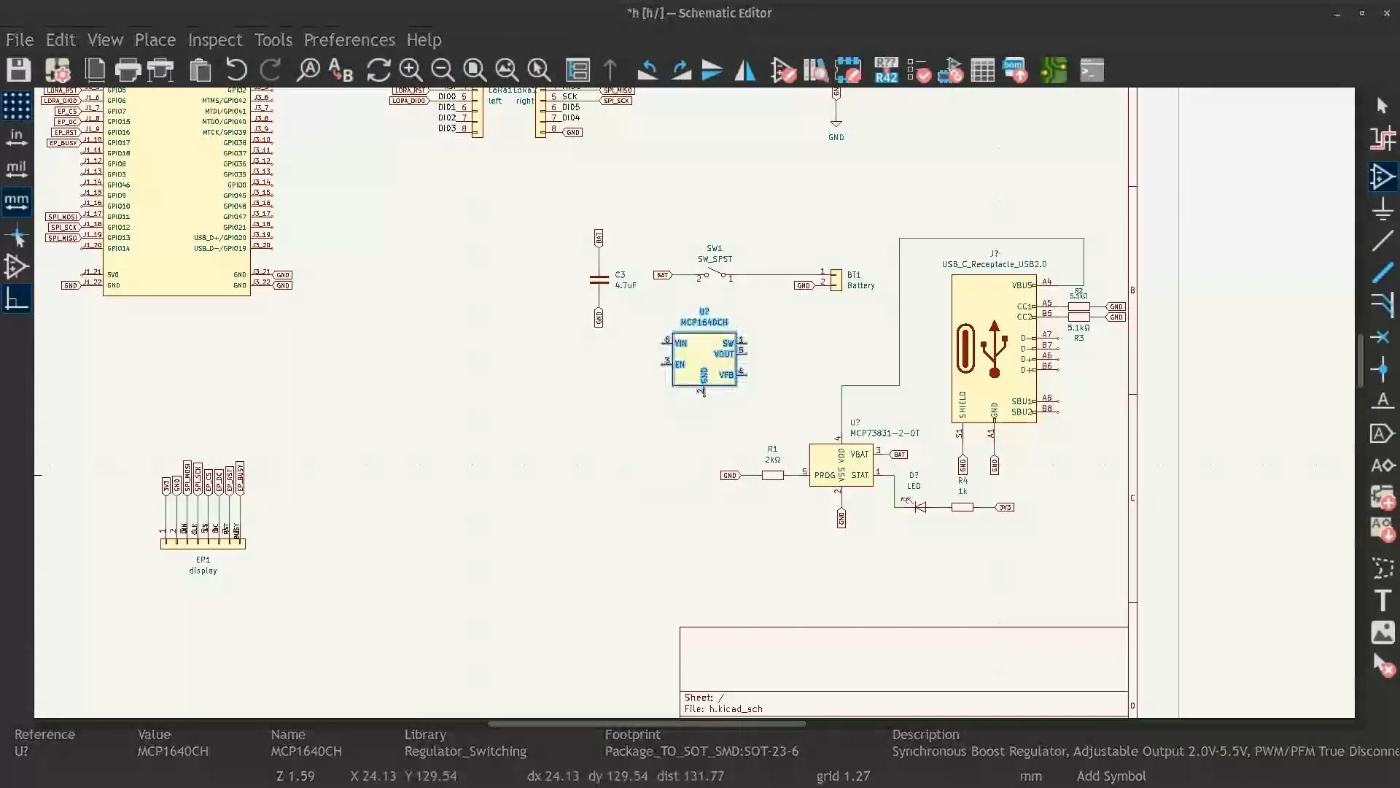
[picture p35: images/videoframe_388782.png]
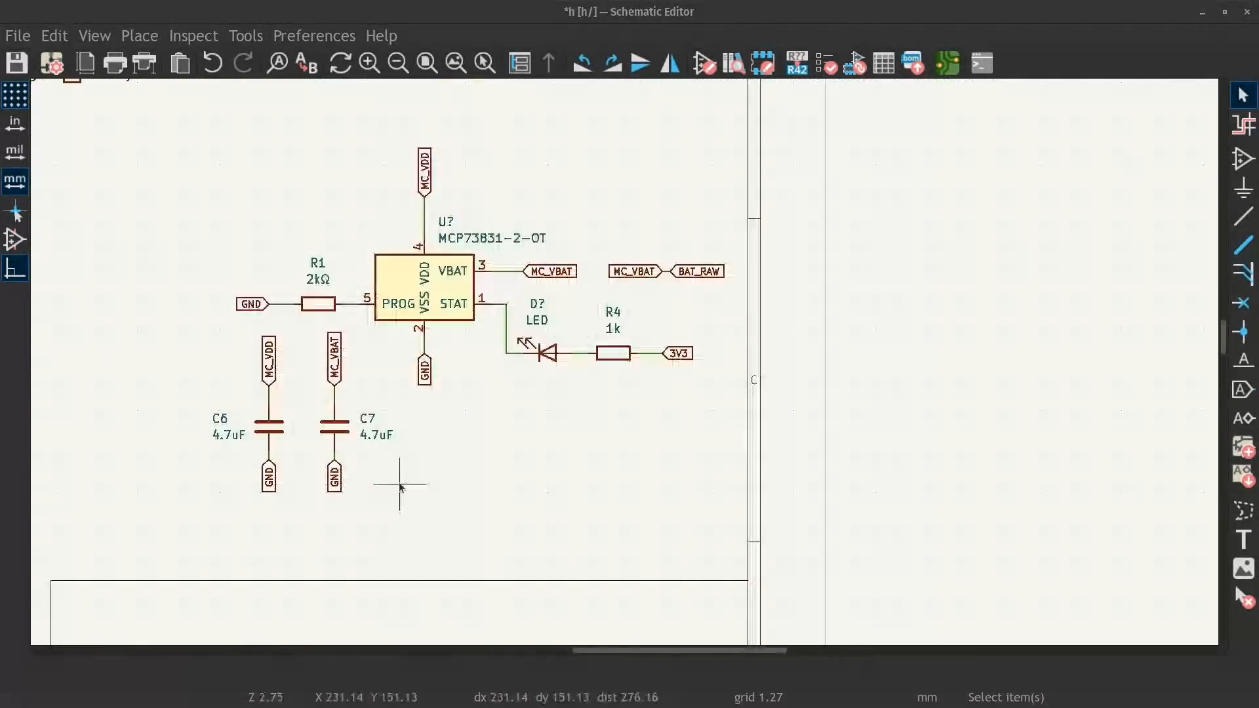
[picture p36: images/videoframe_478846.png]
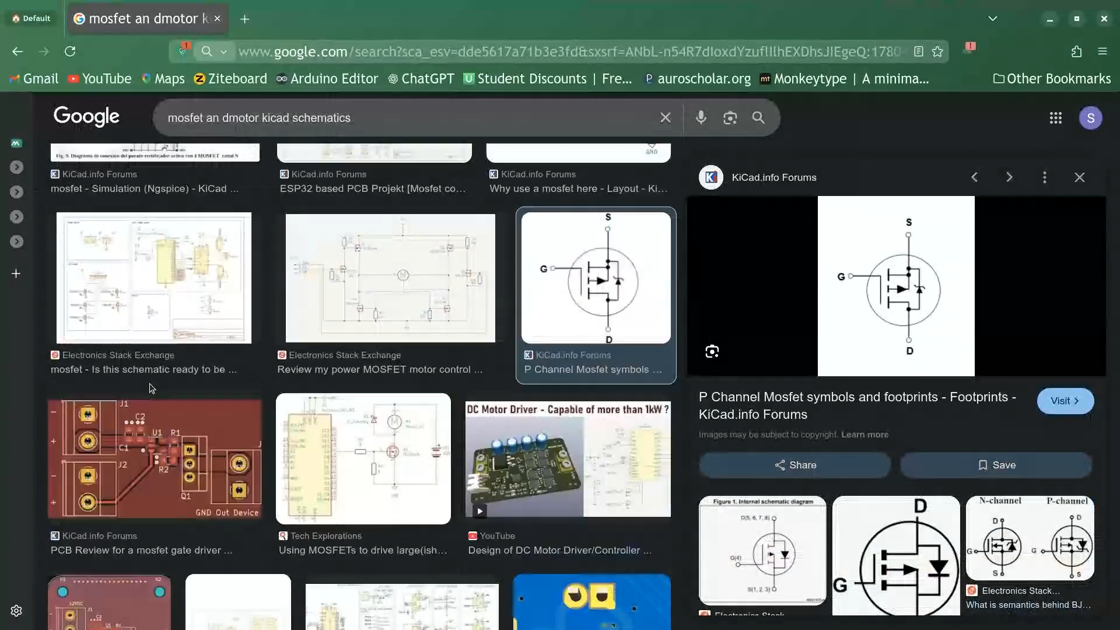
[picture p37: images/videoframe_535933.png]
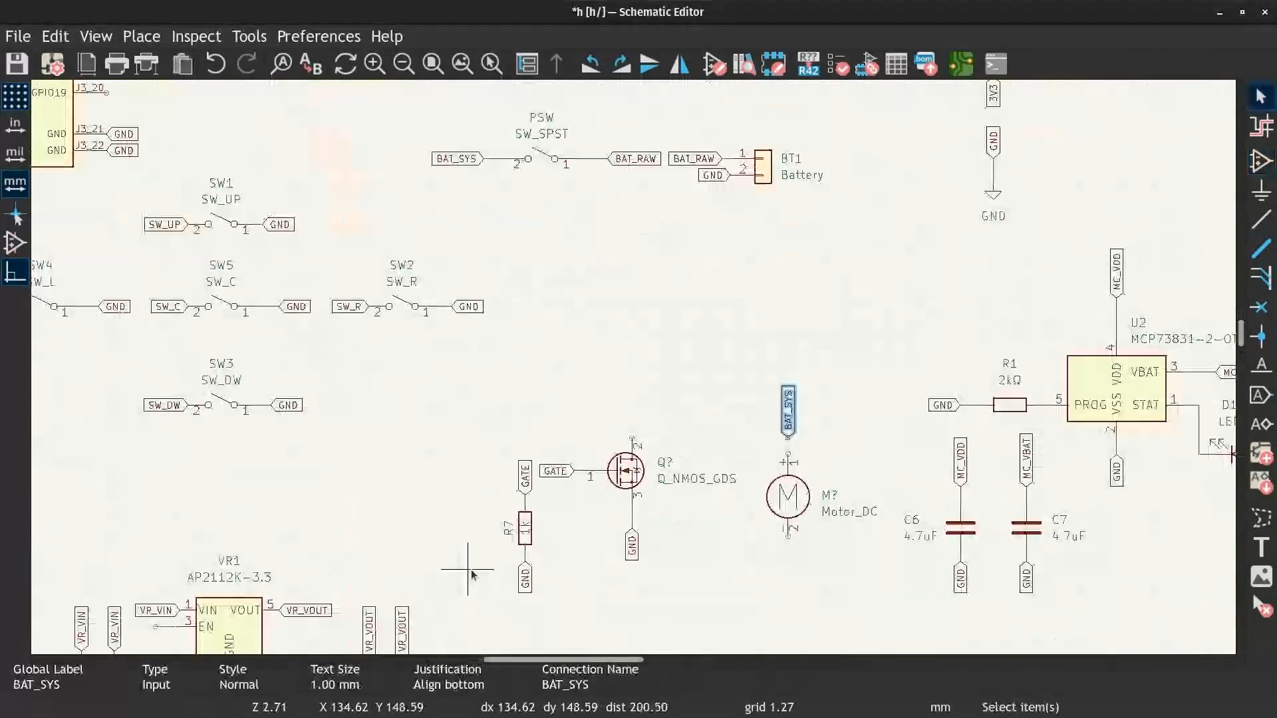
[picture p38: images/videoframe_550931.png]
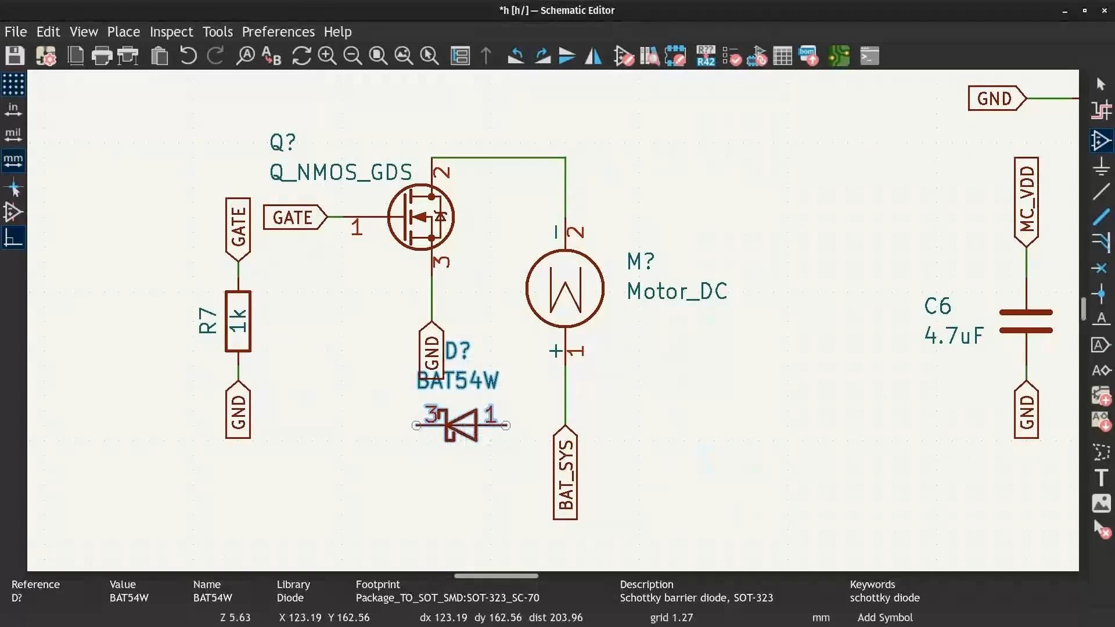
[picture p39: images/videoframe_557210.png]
                   
**Images above are till session 5**

#Session_6

> Now here comes the assembly of footprint on PCB board
> I couldn't figure what to tell about this in Journal, U can refer to Lapse to see assembly.
> Here what I think about why It takes so long to complete the assembly 
> - It is my first PCB and hardware project so I can't figure out what to place where.
> - I didn't know that we can place component both side of the PCB
> I was facing problems with Edge cuts etc

So I started just assembly like there is DEV board and rest of component in sides
then dropped this Ideas as board was too Big.

Then this Dumahh! learned to place component on both sides and get know bout Vias. :dummahh:
so wwhat I thought that i would use header pins for devboad and plac some compo beneath it and places Lora the opposide side. Resistors on sides and soldering pads accordingly.

> Another Dumaah moment!
> I didn't account for routing, why?
> cz I didn't thought about that.
> So I have to re arrange places
> I didn't place capacitors near as possible as input line

ALso I didn't see some basic precause like no High power line near lora etc.

So I replaced capacitor to nearest to its corresponding components and started wire.
 
> You may seem some silly mistakes in lapse while wiring. As I new to KiCad so I didn't knew those. so yeah :sadge:
> Like changes the placement like 3-4 times 
**In this lapse there is some blank and freeze screen Idk why maybe Lapse issue.
**

#Session_7 

So as starting I ran a DRC check as most of wiring/ tracing was done.
>For General Info:
I used *0.25 mm , 0.75 mm & 1.0 mm* tracing according to power need.
Now there was some Silkscreen overlaping for switches fixed that

Then Its time for edge cut, Now I want no extra space in board neither the super edgy corner so I made like stairs step like design on one side and rounded corners.
 
 Then I started Enclosure designing, so I started sketchin' the front face like buttons,display etc in krita u can see this in lapse, also taking some inspo from Pinterest.
 
 a note that the usb foot print doesnt have label assing ed in footprint library it is locally assinged so whenever i updated pcb from schemtatics is renew and none label is shown so i hve to assing it again.

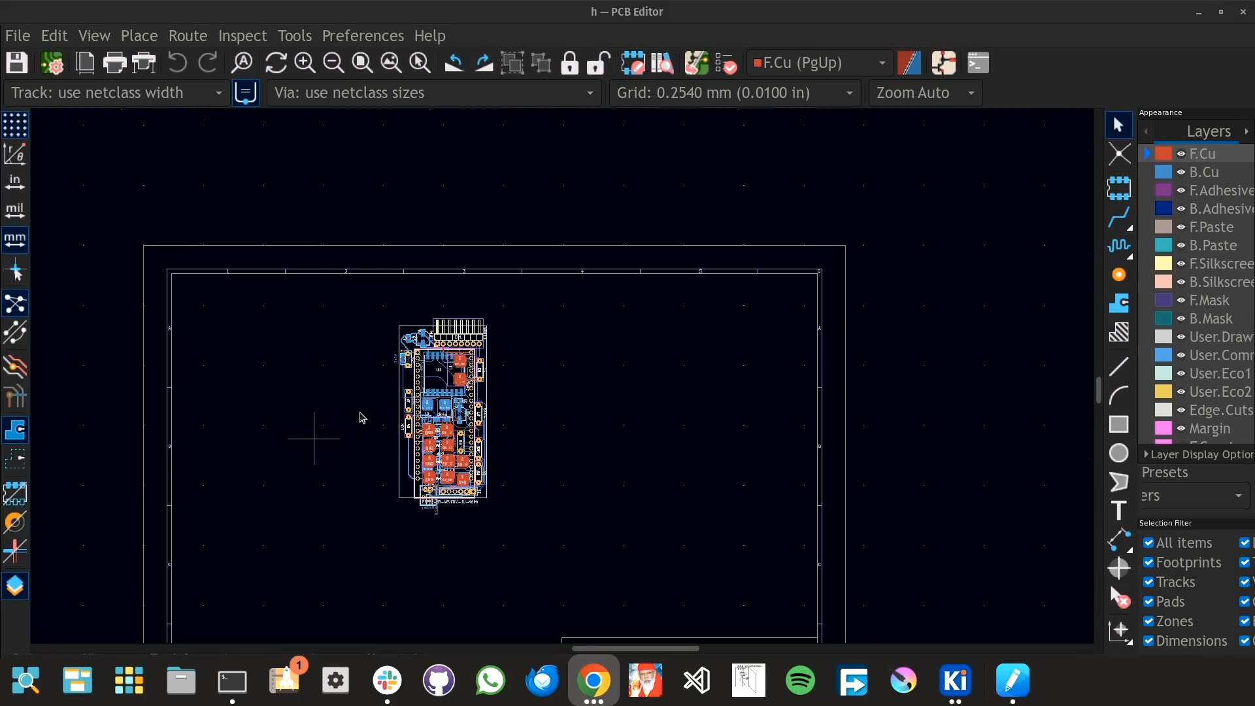
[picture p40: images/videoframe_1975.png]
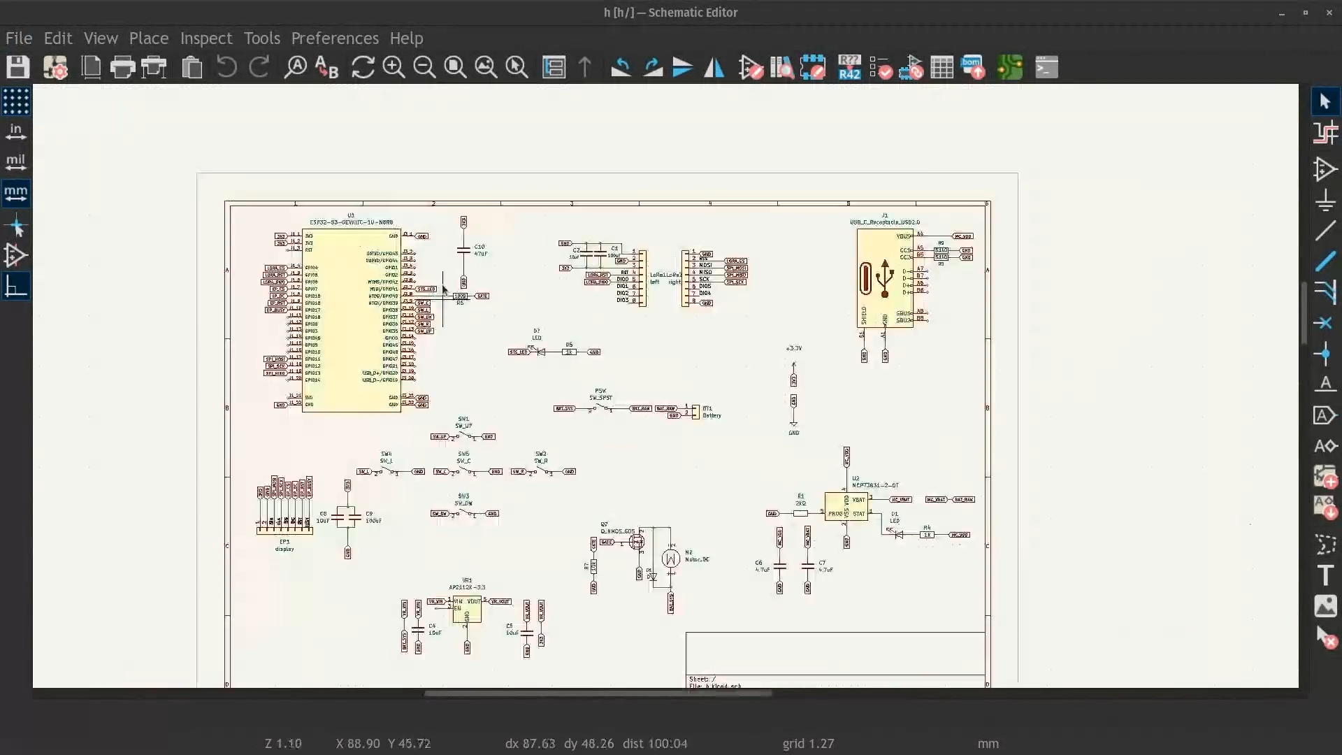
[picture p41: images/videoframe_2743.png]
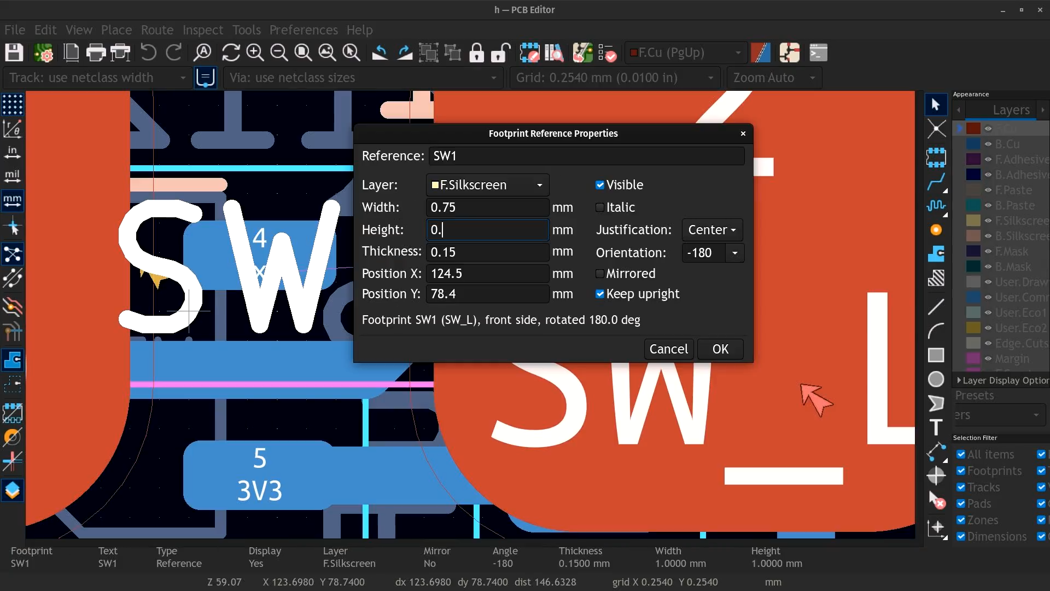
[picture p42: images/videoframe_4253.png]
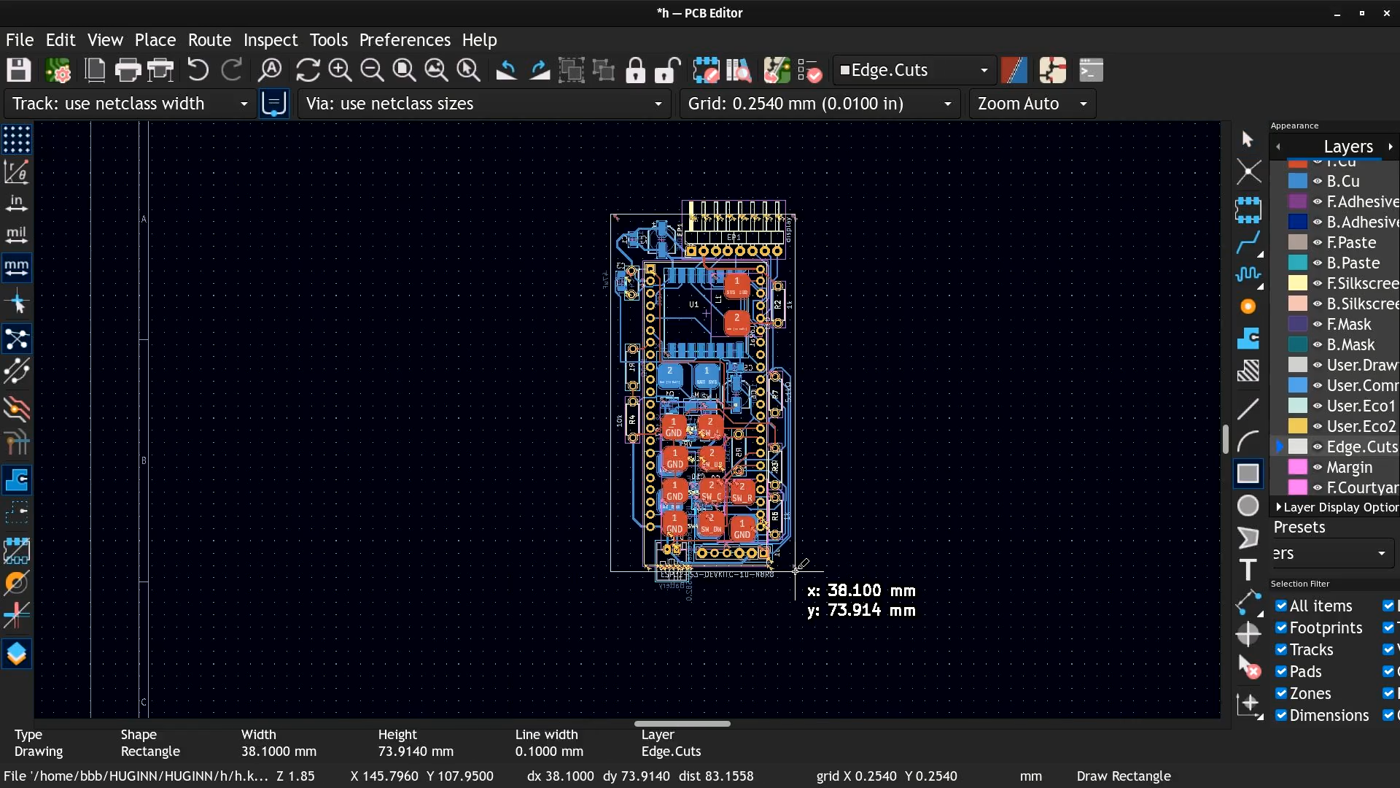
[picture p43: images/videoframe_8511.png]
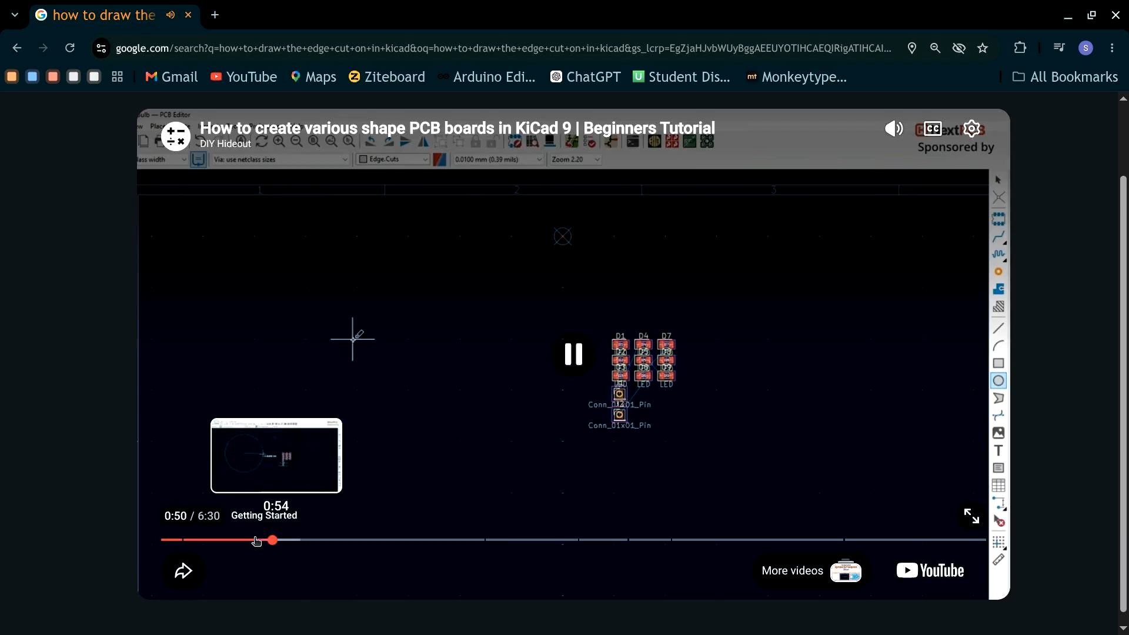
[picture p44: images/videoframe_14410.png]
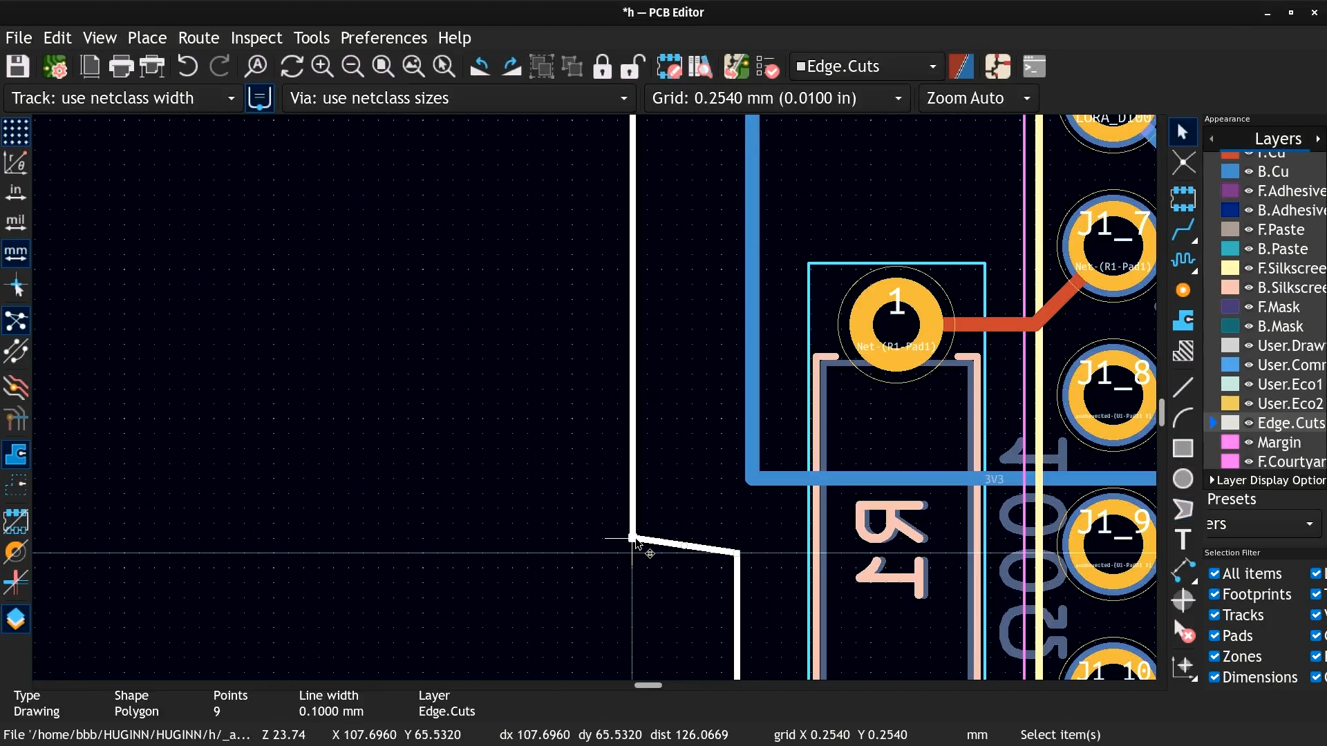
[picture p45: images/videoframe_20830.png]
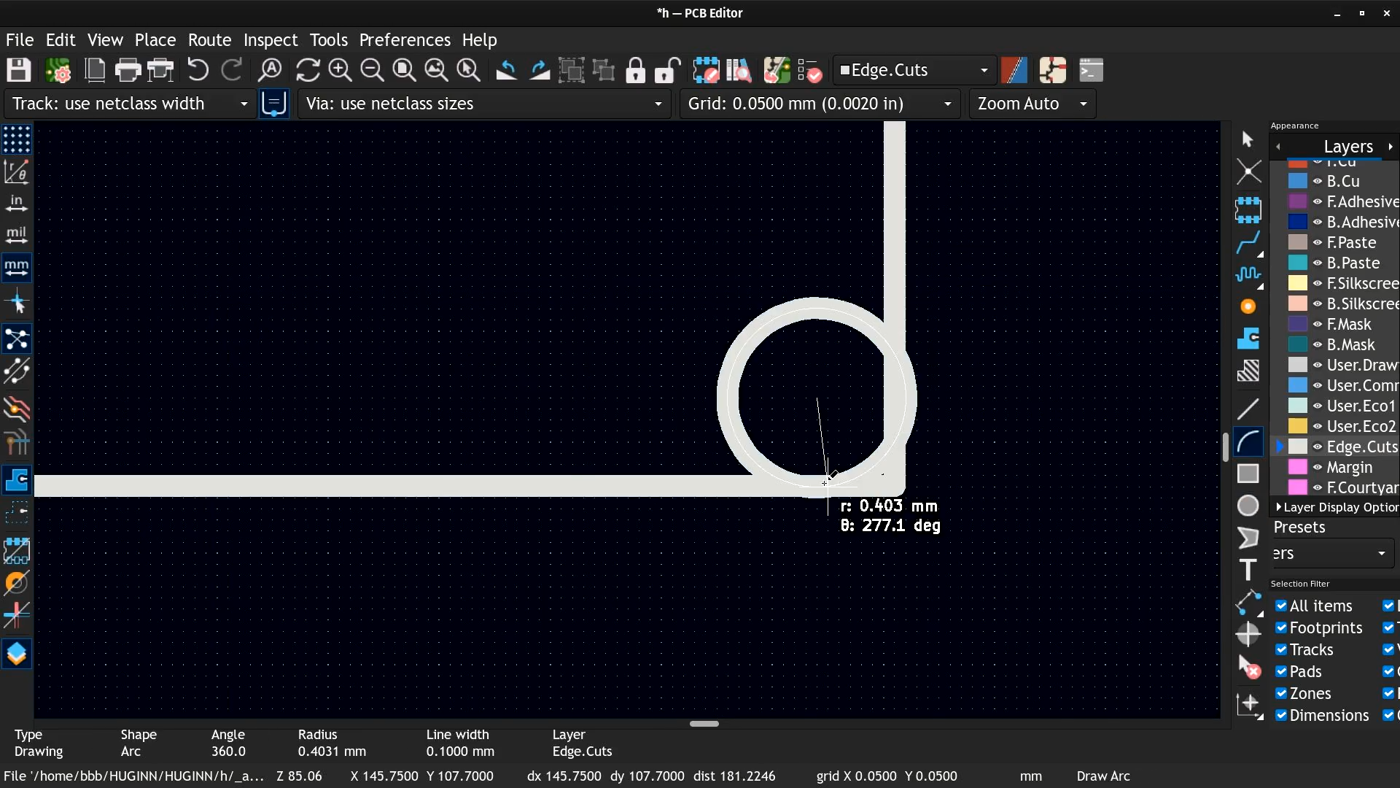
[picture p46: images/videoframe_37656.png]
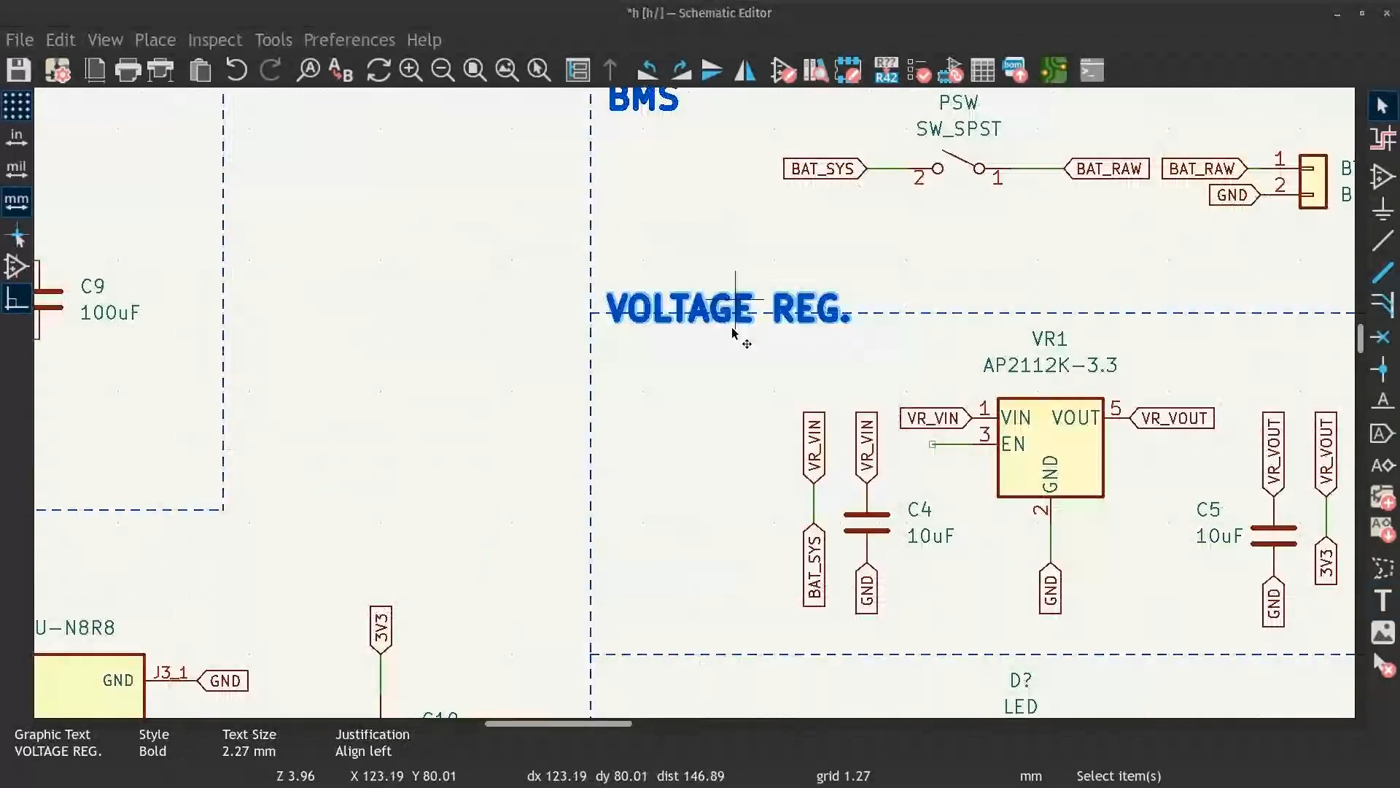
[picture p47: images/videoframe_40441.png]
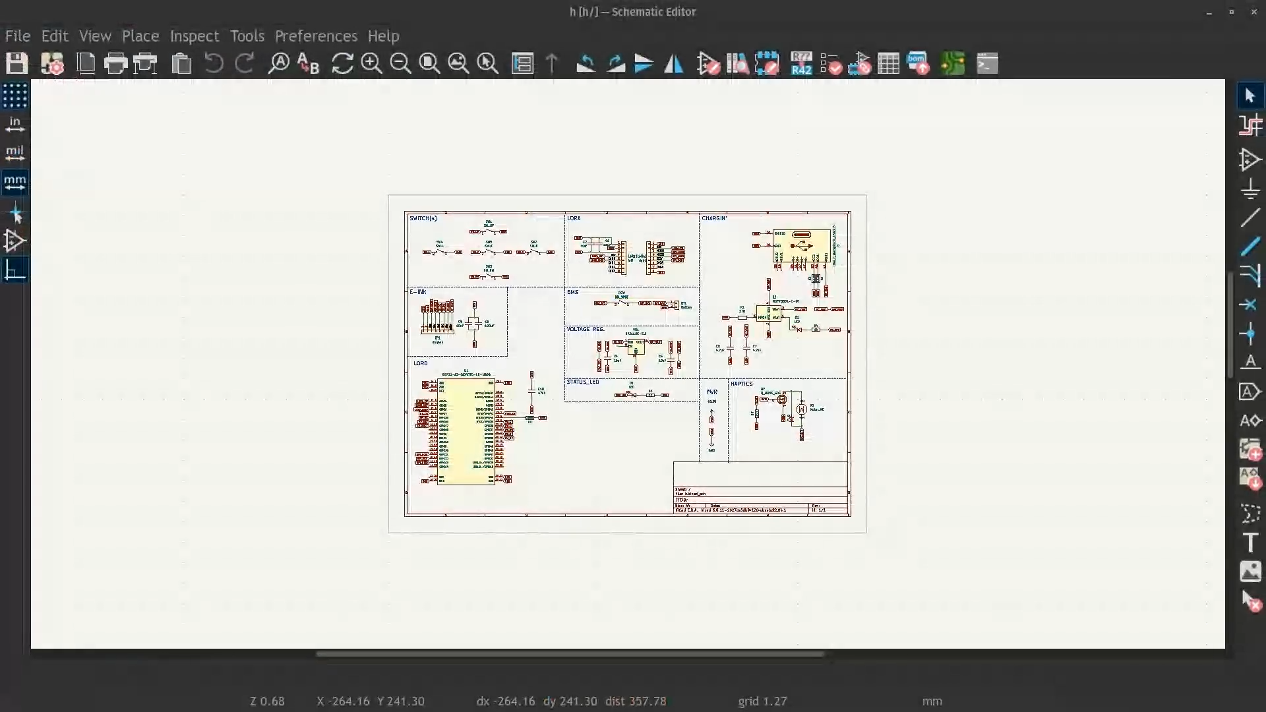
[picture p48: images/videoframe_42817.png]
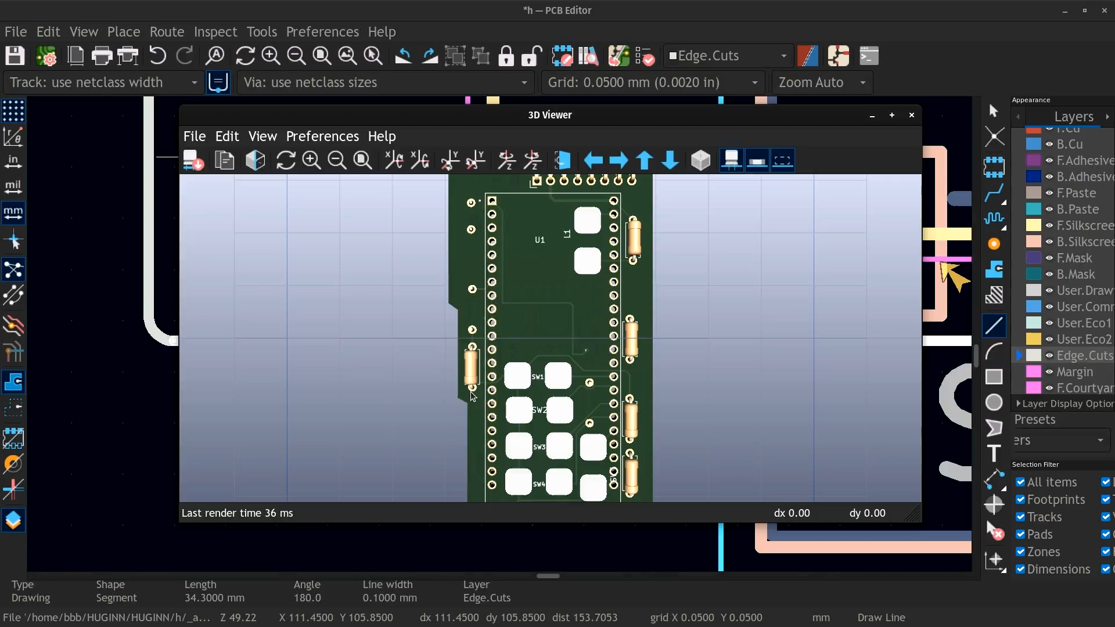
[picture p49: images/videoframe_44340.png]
                                               

# Till JULY 4 (1 Lapse, 1 session)
**[Lapse Link](https://lapse.hackclub.com/timelapse/FahkMhBIB23j) Time Elapsed: 12hrs**

 > This is mostly CAD/Enclosure/Assembly 

#Session_1 
 
After completing the sketch of front face of buttons, colors etc

I ignited CAD and start sketching the Enclosure boundary
> **Context** : For repeated thing in Lapse that may be misinterpreted as Inflation but In fact It first that time I'm using CAD for this extent , previously I only designed a cookie cutter. :hehehehehe:

I started making enclosure by sketch then eclosure boundary then pad it and using *thickness* carved out space.  Althout this ^ step take too long cz i can't figure out how to hollow the box and how to meausure distance
  
And:
  - Fixed very little tracing issue in pcb then try to export it as step but it was just plain green board so LIke i have find better way to get it with 3d component too!

  - Added a Kicad plugin in workbench and imported PCB 3d model and for size purpose fit , It didn't fit by length so i have edit the case. 
  
  - For more Good looking I also add Lora Chip 3d model from web in assembly and removed horizontal header pin for display because of space and connection issue, infact the pin is like this **[Image of pin]** so I wil just solder the wire directly to TH And reimport PCB model.
      
  
  -  Imported E ink display, I researched and changed the display from 2.7 to 2.3 inch cz I didn't account for size of overall pc while designing
  -  And I desinge a [ shape suport for display but later remvoed it as it was eating volume for pcb fitting.

  - Now for supprt of PCb and display strudity i will not use screw support cz of space constraints therefore i added a wall-slab with screw groove and will use sillicon pad at end of screww to just press the both PCB and screen into position. U may seem litle google search her , was bout Freecad doubt & display sizings.

 - Sketch out display size on front of case and then chamfer it for edgy looks.
 - 
 -      
 - Imported navigation push buttons adn arrange them as best fit and Aesthetics.
 -  
 - Traced a border outline , actually i changed it few times like once I missed then correct face,once I left like empty space in b/w button so ihave also remove the area unused in b/w button so it can fit.
- Then pocket out the area , now it was time to support the buttons thought I will glue them to frame but as it will be pressed hard repteadly I desinged a frame like rising from base and then going slab like above the buttons but only halfway , for another halfway i made another one same ,not symetrically but yeah then holes above it to push the button in place by using screws. I made it in two part to little liberty while building the screw hole can be repositing at least to some magnitude.
- (This actually took soo much time like idk how aling to different body for perfect alingment)
- 
  


#Session_2
 
 I started making 
power button for so as intially in sketch I designed it was two circle of different size on will ortae axialy. I go for same though had some issu in sketching it. then i added h vertical center to center bar and make it slanting in side of small circle for btter grip.

- Then placed in it in correct palce on front face of enclosure
- carved out a place holder of 1.5 mm in front face to hold button and in big angle to button can slige to n fro. then pocket out a arc hole to lead a pillar like pad from front part of button on upper side and then extrude a side way tapered increasing to fix magnet there
- Imported hall sensor and 
- sketched a support three way like a helmet for hall sensor.

(Thouth I face a lots of contraint issue in this sketch)
          

#  July 4 (1 session, 1 lapse)
**[Lapse Link](https://lapse.hackclub.com/timelapse/i13NdgKe-hXV) Time Elapsed: 2hrs 24 mins**
In this i tried to make a grip of magnet face holder but dropeed as it was alr too litte area

## button top design times
now it was time to design to design button top
So I started with first pocketing out a square for send button, I forgot bout that :dumb: so then I started button design 
so for navigatin istead of seprate button for ech side used all arrow adn spear like design to go for
sketch it , pad it, aling it to the buttons and then pocket out holder holes for then and then fit it in assembly.then fillet it from all sides
same for send button but It was of triangle shape though.
> This took a little longer to plan the design and aling and sketch as i want it to look good 
Then:
- I alr iported a 3.7 v Li-po batter but ididnt fit soI found a another one but could not find its 3D model so i statred to made one , In this stage i learne hoe to colro faces and body in FreeCAD
  
Then, Its time to make a back panel for Encosure
so I first sketch out and then pocket out a rim inisde of wall of enclosure ant hen sketh it out and pad it to full panel for sketch.

For support and fixing panel I use the same slab hole that'll use to clamp the pcb and scrren so a single screw will hold the panel, display and pcb
 then I colored all the faces .
 
 Then i made cutout for type C but I cant find real cutout dimentsion it fixed later when i imported a type c break board, but imported breakout board's pcb was dislocated so i mad eon with correct dimension and replaced it
           

# July 16 (1 Lapse and 1 session)
**[Lapse Link](https://lapse.hackclub.com/timelapse/NnLJkcKzMWgB) Time Elapsed: 2hrs 16 mins**

Fist thing I saw many issue
Like 
>- the frame and back panel are in same body
we need it different baody to print seprately and 

>- The screww holes was of wring diameter, as for M2 screw with self tapping I need 1.6 +- 0.05 mm bot Idk why I use 2.1 mm everywhere.

> - As I removed the supporting slab cz it was too space consumeing and not supporting firmlyso There isn't any support for Display .

>- the power button is like axial rotation but display FFC strip is blocking its way + the Momentary switch is not alinged to pressing pad

>- There isn;t any hlding an rotaing mechanishm for Pwer switch

How do i Solve them? :ponders:
So first I can't remove the back panel which is *PAD* in a body if dlete it it will break the body
so what i did is i use external geometry selction on fce of panel out and pocket it out

then use a shape binder of the frame in another body and make the bakc panel with correct dimension

2. For screww Holes i just openned the skect and pocket of every hole and resketch to 1.65mm of diameter and re- pocket

3. I made a two thin flecxible strip , little shorter than display height for firm grip.
4. Now comes the most time consuming part. So, First I forgot that Hall sensor require a GPIO pin to work, though I could assing one in PCB but problem was i want complete power shut off switch. But I Edit the support for Hall sensor then add a momentary switch ( actually i didn't know that this thing exists :blyat:)

Now Bout switch, 
- So first switch is made of two sketch so I have to move them seprately and pocket them out seprately
- Now I need to make a holding system for switch rotation and so i did like a pocket for M2 screww obv with self tapping dimensions that will be screwed little loose vertically so that button can rotate.
- Then comes the padd part that will press the momentary switch so delete the pad before and restart from scratch pad a long pad then the pad

A dumb problem here i added a pad on base or power button but after print how some one can get it fit inside so i have to make the same pad in another body
 so later I undo it and add and export it as another body ( though i didn't have lapse for this specific task)


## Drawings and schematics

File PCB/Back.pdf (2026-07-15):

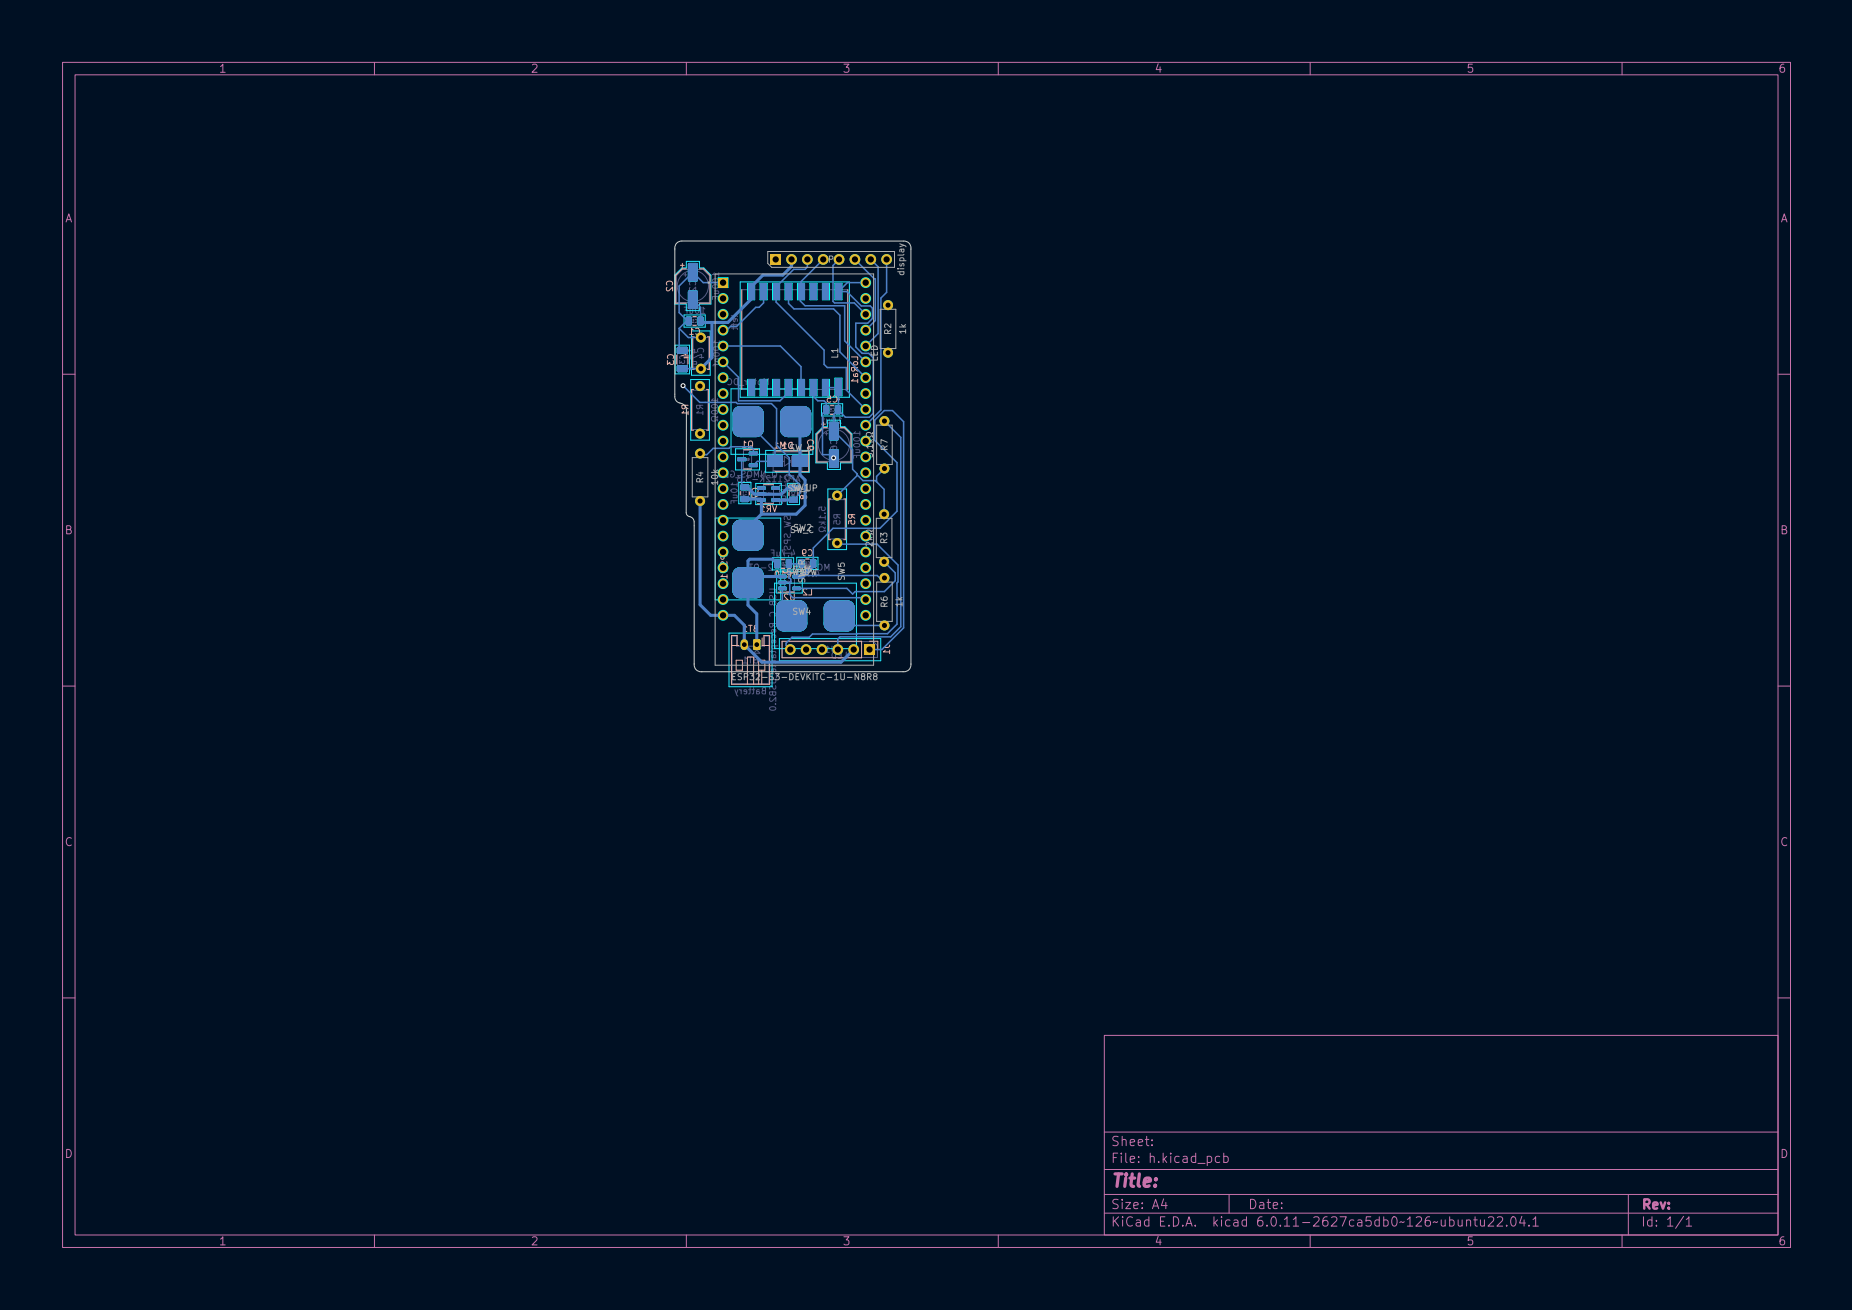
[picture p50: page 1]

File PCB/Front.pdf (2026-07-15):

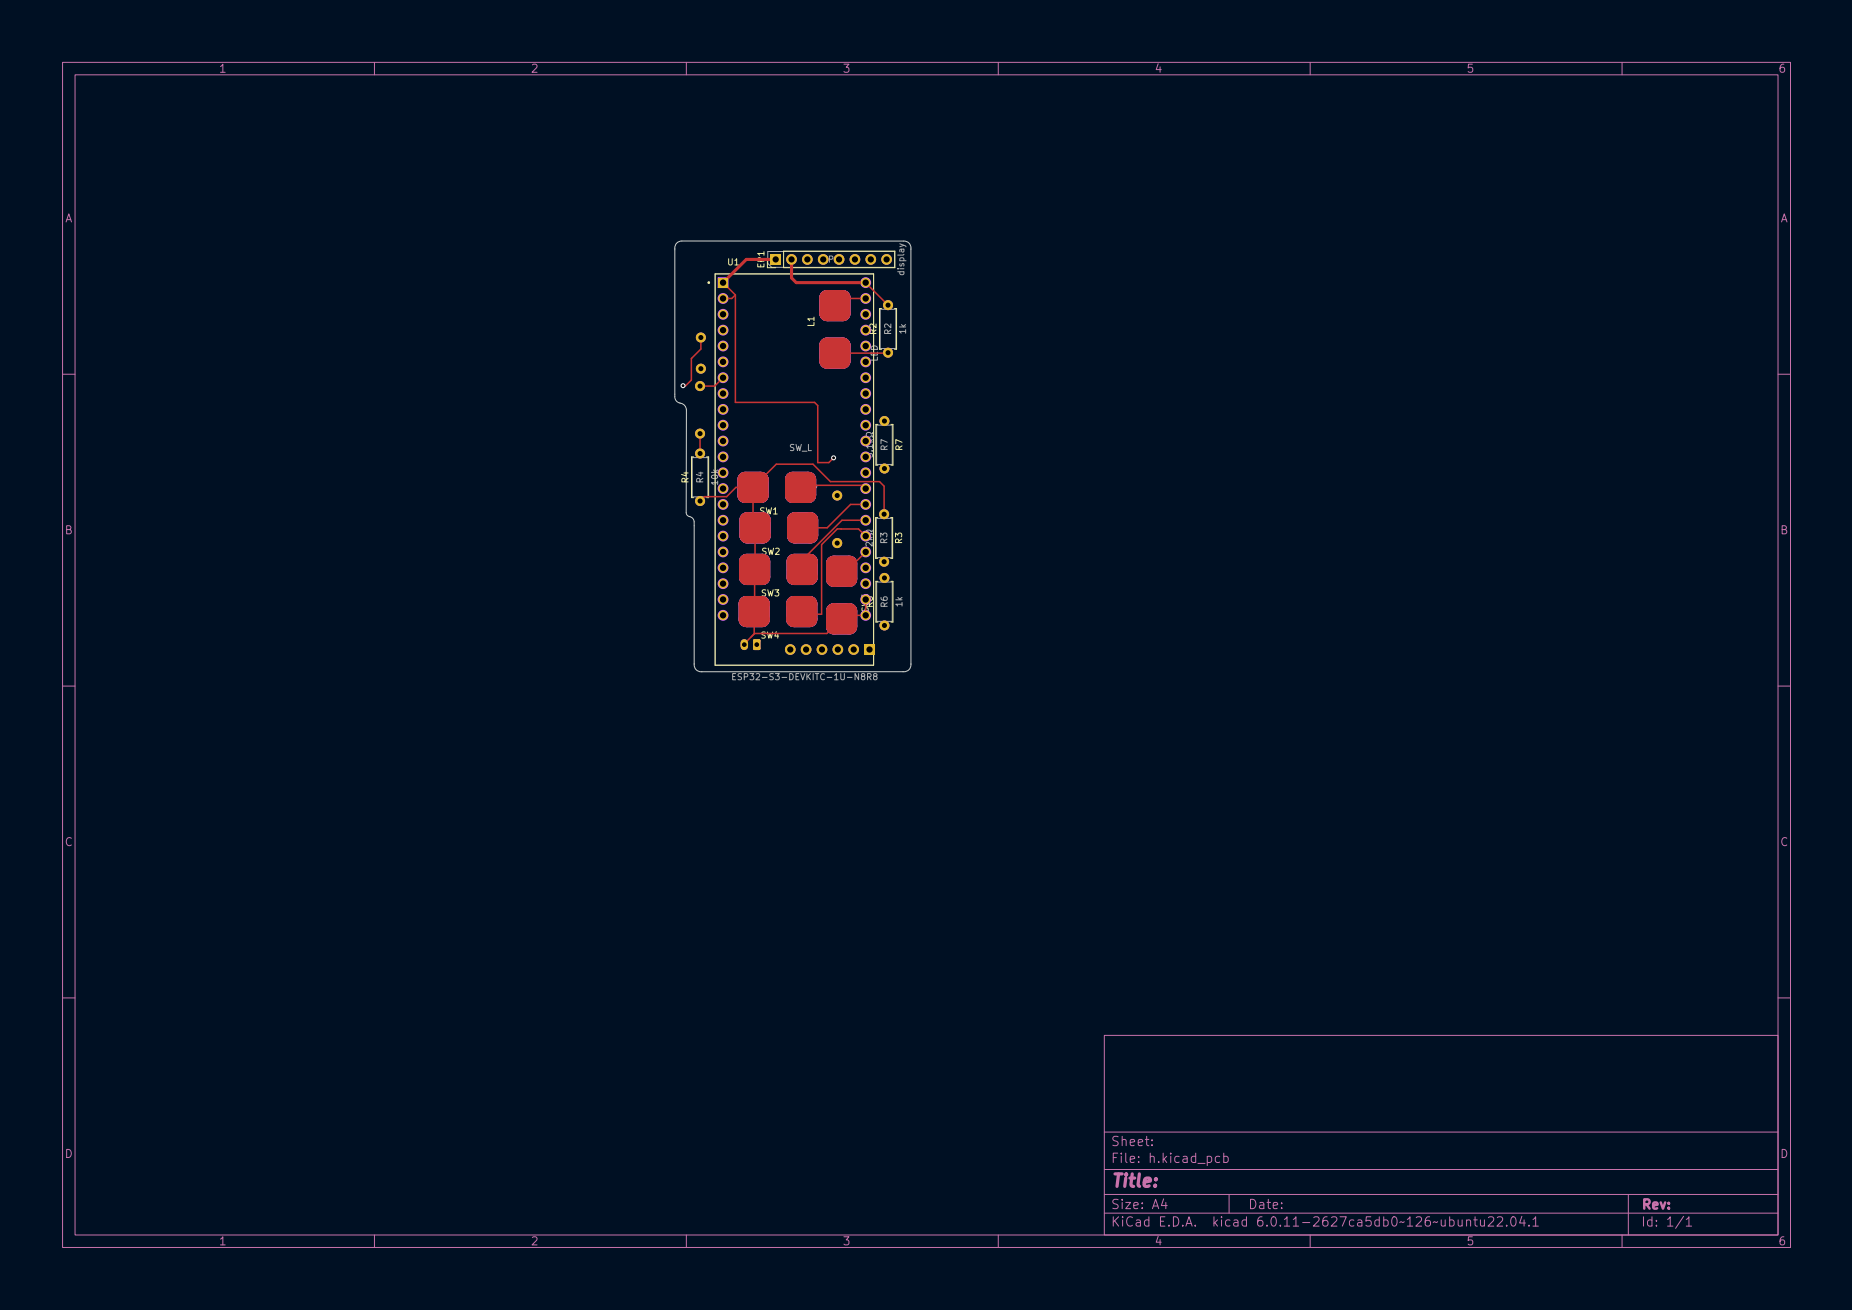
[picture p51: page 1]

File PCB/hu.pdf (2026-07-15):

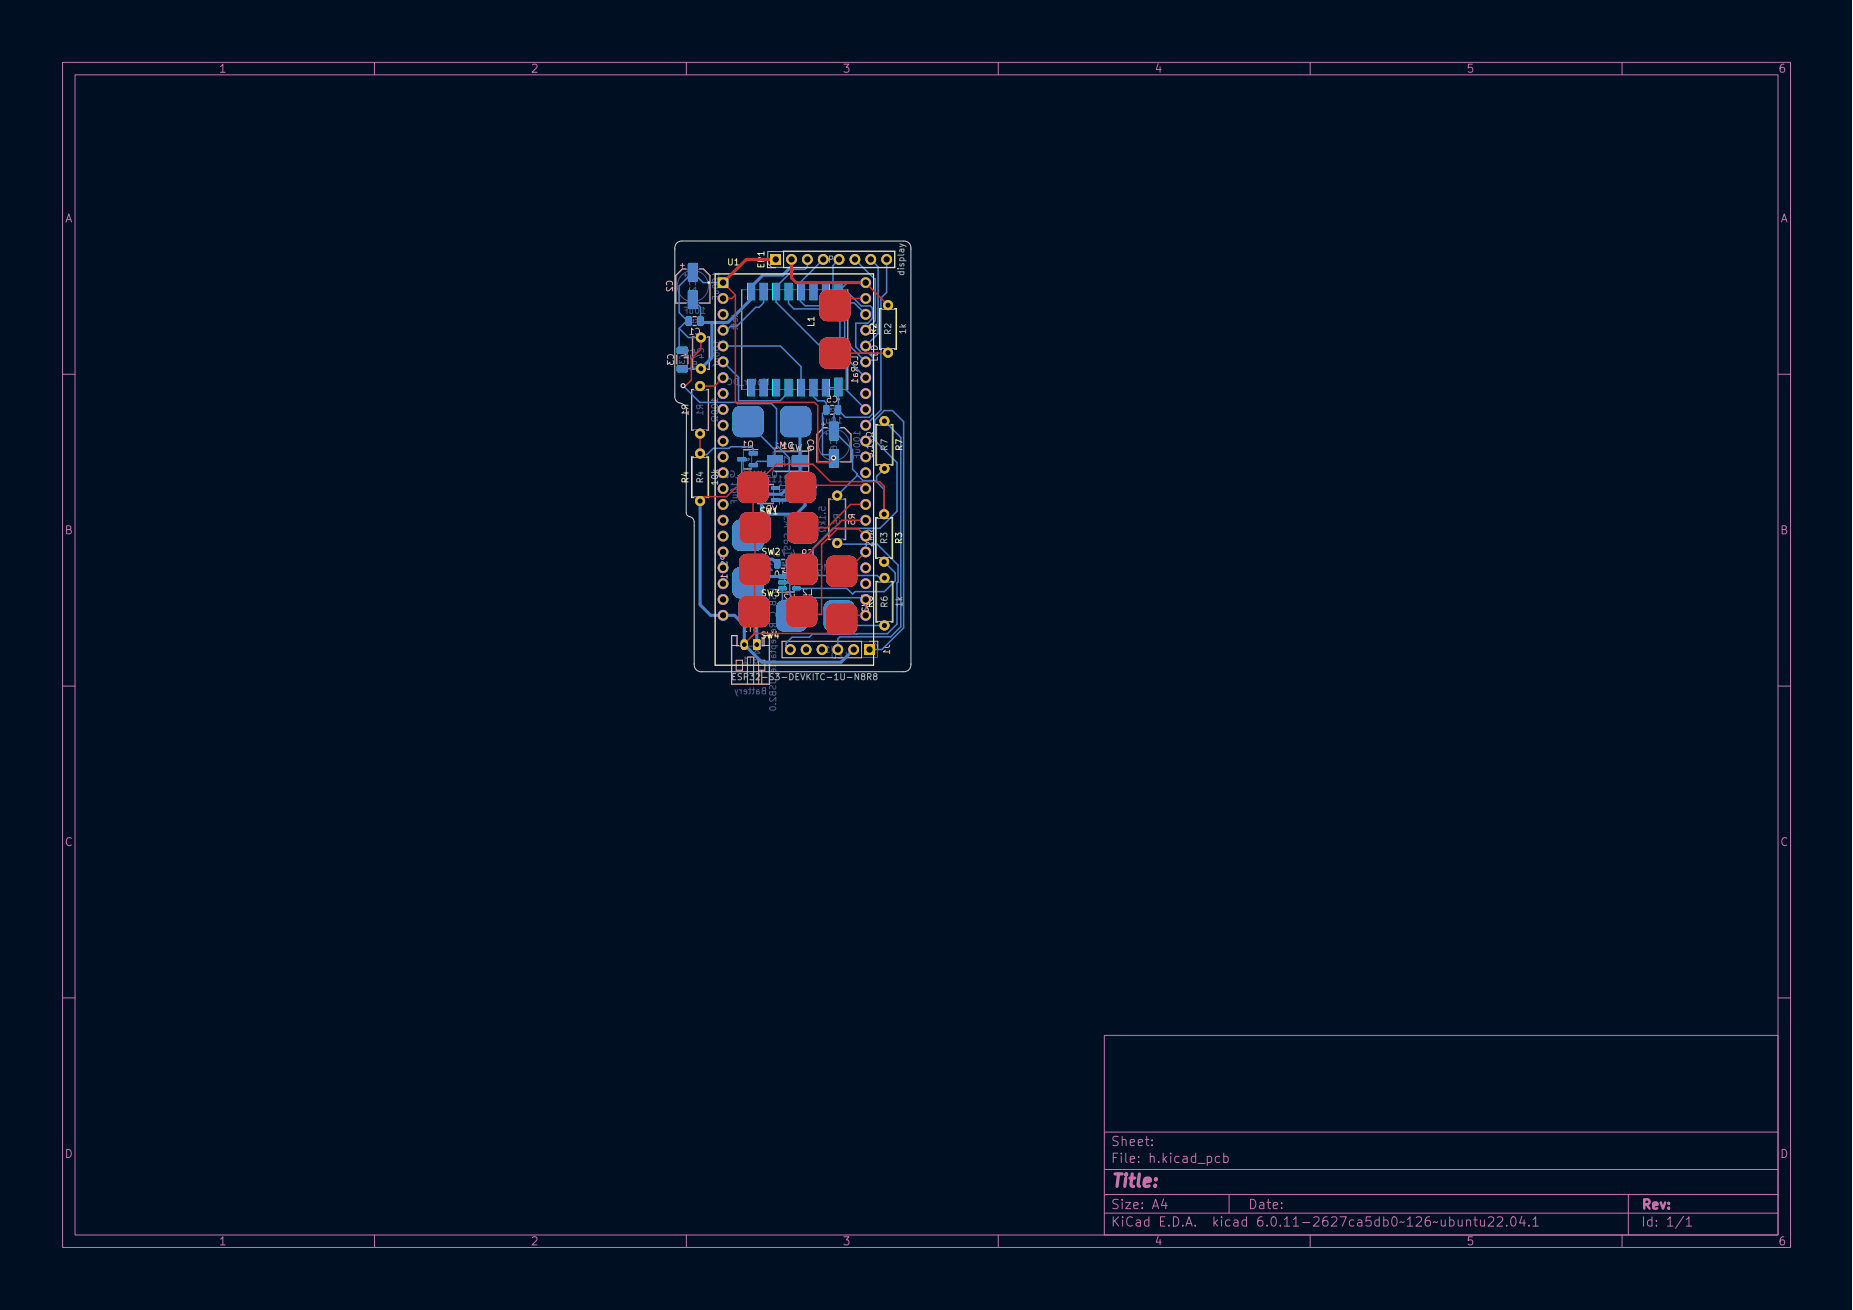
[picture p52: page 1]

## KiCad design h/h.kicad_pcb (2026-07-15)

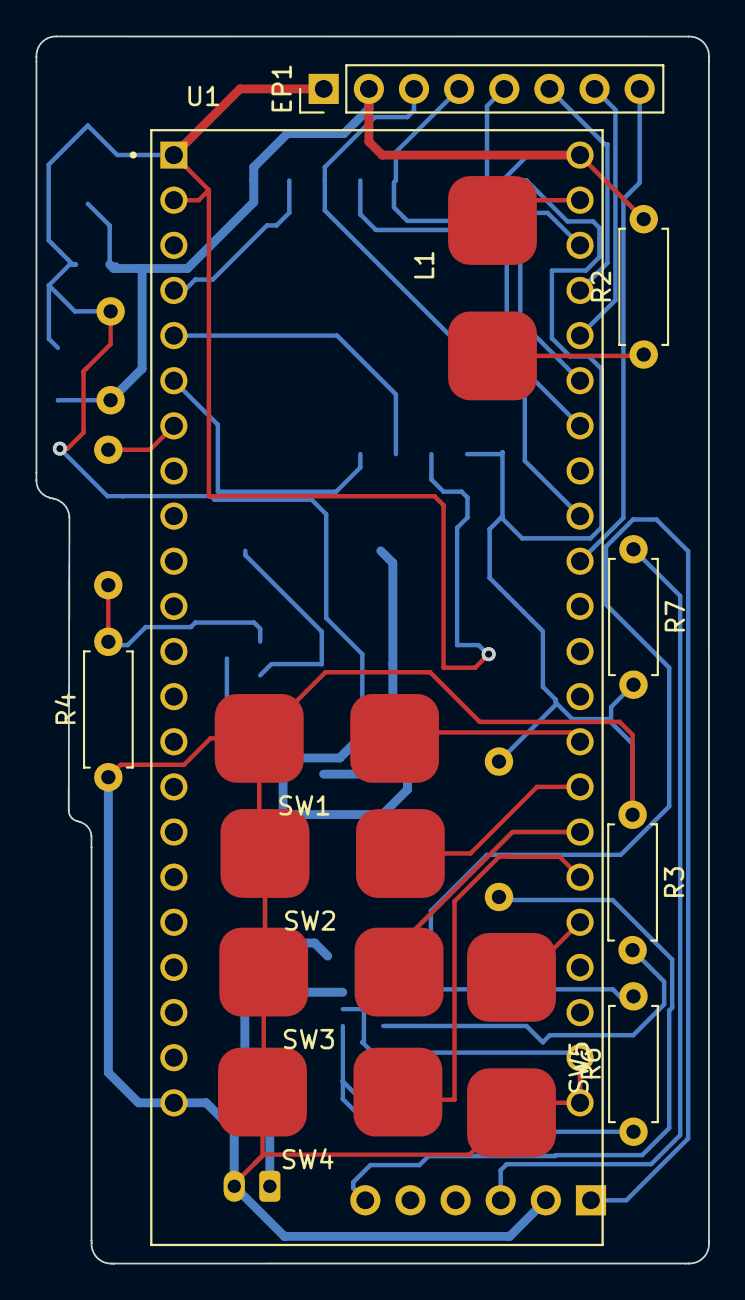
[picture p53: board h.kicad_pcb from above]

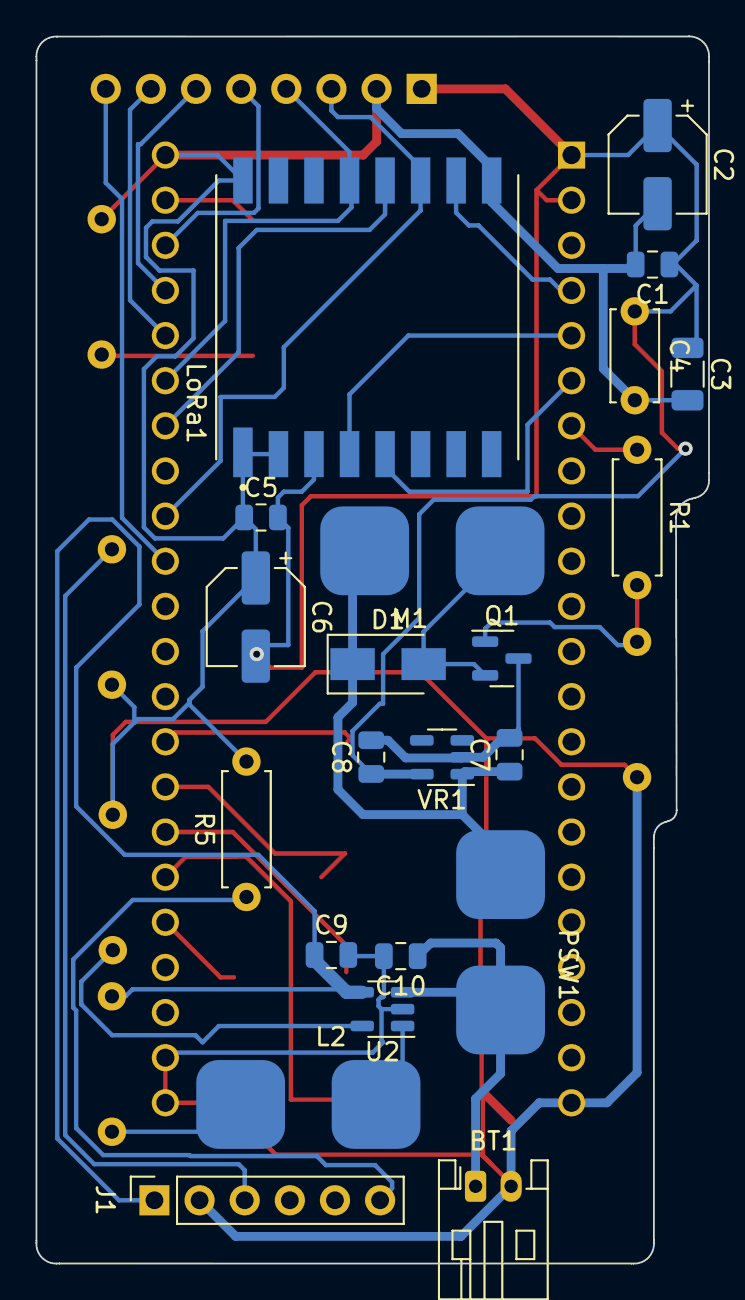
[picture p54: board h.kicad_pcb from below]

Board: 2 copper layers, 37.9 x 69.1 mm, 35 parts (22 on the bottom side), 28 nets.

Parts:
BT1: Battery; JST_PH_S2B-PH-K_1x02_P2.00mm_Horizontal
C1, C7, C8: 10uF; C_0805_2012Metric
C2, C6: 100uF; CP_Elec_5x5.3
C3: 47uF; C_1206_3216Metric
C4: 100nf; C_Disc_D5.0mm_W2.5mm_P5.00mm
C5: 10uf; C_0805_2012Metric
C9, C10: 4.7uF; C_0805_2012Metric
D1: D; D_SMA
EP1: display; PinHeader_1x08_P2.54mm_Vertical
J1: USB_C_Receptacle_USB2.0; PinSocket_1x06_P2.54mm_Vertical
L1, L2: LED; SolderWirePad_1x02_SMD_5x5mm
LoRa1: left; MODULE_RA-02_LORA
M1: Motor_DC; SolderWirePad_1x02_SMD_5x5mm
PSW1: SW_SPST; SolderWirePad_1x02_SMD_5x5mm
Q1: Q_NMOS_GDS; SOT-23
R1: 100Ω; R_Axial_DIN0207_L6.3mm_D2.5mm_P7.62mm_Horizontal
R2, R6: 1k; R_Axial_DIN0207_L6.3mm_D2.5mm_P7.62mm_Horizontal
R3: 2kΩ; R_Axial_DIN0207_L6.3mm_D2.5mm_P7.62mm_Horizontal
R4: 10k; R_Axial_DIN0207_L6.3mm_D2.5mm_P7.62mm_Horizontal
R5, R7: 5.1kΩ; R_Axial_DIN0207_L6.3mm_D2.5mm_P7.62mm_Horizontal
SW1: SW_L; SolderWirePad_1x02_SMD_5x5mm
SW2: SW_UP; SolderWirePad_1x02_SMD_5x5mm
SW3: SW_C; SolderWirePad_1x02_SMD_5x5mm
SW4: SW_DW; SolderWirePad_1x02_SMD_5x5mm
SW5: SW_R; SolderWirePad_1x02_SMD_5x5mm
U1: ESP32-S3-DEVKITC-1U-N8R8; ESP32-S3-DEVKITC-1-N8R8
U2: MCP73831-2-OT; SOT-23-5
VR1: AP2112K-3.3; SOT-23-5

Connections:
3V3: C1.1, C2.1, C3.1, C4.1, C5.2, C6.2, C8.1, EP1.1, LoRa1.3, U1.J1_1 (3V3), U1.J1_2 (3V3), VR1.5 (VOUT)
BAT_RAW: BT1.1, C10.1, PSW1.1 (A), U2.3 (VBAT)
BAT_SYS: C7.1, D1.1 (K), M1.1 (+), PSW1.2 (B), VR1.1 (VIN)
EP_BUSY: EP1.8, U1.J3_10 (GPIO38)
EP_CS: EP1.5, U1.J3_3 (U0RXD/GPIO44)
EP_DC: EP1.6, U1.J3_4 (GPIO1)
EP_RST: EP1.7, U1.J3_5 (GPIO2)
GATE: Q1.1 (G), R1.2, R4.2
GND: BT1.2, C1.2, C2.2, C3.2, C4.2, C5.1, C6.1, C7.2, C8.2, C9.2, C10.2, EP1.2, LoRa1.1, LoRa1.2, LoRa1.9, LoRa1.16, Q1.3 (S), R2.2, R3.1, R4.1, R5.2, R7.2, SW1.1 (A), SW2.1 (A), SW3.1 (A), SW4.1 (A), SW5.1 (A), U1.J1_22 (GND), U1.J3_1 (GND), U1.J3_21 (GND), U1.J3_22 (GND), U2.2 (VSS), VR1.2 (GND)
LORA_CS: LoRa1.10, U1.J1_4 (GPIO4)
LORA_DI00: LoRa1.5, U1.J1_6 (GPIO6)
LORA_RST: LoRa1.4, U1.J1_5 (GPIO5)
MC_VDD: C9.1, R6.2, U2.4 (VDD)
unnamed: D1.2 (A), M1.2 (-), Q1.2 (D)
unnamed: L1.2 (A), R2.1
unnamed: L2.1 (K), U2.1 (STAT)
unnamed: L2.2 (A), R6.1
unnamed: R1.1, U1.J1_7 (GPIO7)
unnamed: R3.2, U2.5 (PROG)
SPI_MISO: LoRa1.12, U1.J3_7 (MTDI/GPIO41)
SPI_MOSI: EP1.3, LoRa1.11, U1.J3_9 (MTCK/GPIO39)
SPI_SCK: EP1.4, LoRa1.13, U1.J3_6 (MTMS/GPIO42)
STS_LED: L1.1 (K), U1.J3_2 (U0TXD/GPIO43)
SW_C: SW3.2 (B), U1.J3_16 (GPIO48)
SW_DW: SW4.2 (B), U1.J3_17 (GPIO47)
SW_L: SW1.2 (B), U1.J3_14 (GPIO0)
SW_R: SW5.2 (B), U1.J3_18 (GPIO21)
SW_UP: SW2.2 (B), U1.J3_15 (GPIO45)

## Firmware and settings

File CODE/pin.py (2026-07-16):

lora_cs = 4
lora_rst = 5
lora_d0 = 7

spi_sck = 42
spi_miso = 41
spi_mosi = 39

ep_cs = 44
ep_dc = 1
ep_rst = 2
ep_bsy = 40

sw_l = 0
sw_up = 45
sw_c = 48
sw_dw = 47
sw_r = 21
sts_led = 43
mtr_gt = 6

fsfmnjgs
oprtyh

n4366538
566

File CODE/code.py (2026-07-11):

import time
import display
import buttons
import lora
import led
import motor
import msg

sel = 0


def alert(txt):
    led.on()
    motor.on()
    display.shw_msg(txt)
    time.sleep(2)
    motor.off()
    time.sleep(3)
    led.off()


def run():
    display.init()
    lora.init()
    display.shw_menu(msg.codes, sel)

    while True:
        if buttons.up_prsd():
            move(-1)
        elif buttons.dw_prsd():
            move(1)
        elif buttons.snd_prsd():
            cd = msg.codes[sel]
            lora.send(cd)
            time.sleep(0.3)

        cd = lora.recv()
        if cd is not None:
            txt = msg.lookup(cd)
            alert(txt)
            display.shw_menu(msg.codes, sel)

        time.sleep(0.1)


def move(step):
    global sel
    sel = (sel + step) % len(msg.codes)
    display.shw_menu(msg.codes, sel)

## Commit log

2026-06-27 check desc/
    -completed schematics
    -PCB design and routing
    -sanity check
    -ERC / DRC checked
    [frame.FCStd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]
2026-06-30 Check desc.
    many things
    in devlog
    in short
    added button
    it support
    power button design
    and it carving for rotation.
    [frame.FCStd]
2026-07-04 Check desc.
    add button support
    slider button
    hall sensor support
    and its button
    support for magner.
    more
    [frame.FCStd]
2026-07-07 check desc.
    final pcb edit removed the header pin used smd pads
    for usb
    added usc cuting and breadbout board
    [frame.FCStd, h.kicad_pcb]
2026-07-11 check desc
    add code file and organize rest for main firmware
    and completed assembly
    [frame.FCStd, h.kicad_pcb]
2026-07-11 check desc.
    Update display.py
    and write pin out
2026-07-11 check desc.
    write motor.py and msg.py
2026-07-14 check desc.
    some changeslike differ bodyf or back panel and magnet pusher etc in cad
    and journal
    [frame-Body.step, frame.FCStd]
2026-07-14 check desc.
    Fix button alling ment and sketch reloction and button spine too! cz it was coing with led ffc strip
    [Assembly.FCStd, frame-Body.step, frame-Body.stl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]
2026-07-15 check desc.
    - change the Back panel design
    - Imported Dev board to assembly
    [Back_panel.step, Back_panel.stl, Button_support.step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]
2026-07-16 check desc.
    created momentary button pad as another body
    [Power_button.step, Power_button.stl, Power_switch.stl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]
2026-07-16 check desc.
    wrote whole journal
    wrote the Readme
    and fixed some code files
    [BOM.csv, BOM.ods, h.csv]
2026-07-16 check desc.
    Fixed files and journal
    [code.py, display.py, lora.py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]
2026-07-16 check desc.
    fix readme
    added a assembly .step
    [frame.FCStd]
